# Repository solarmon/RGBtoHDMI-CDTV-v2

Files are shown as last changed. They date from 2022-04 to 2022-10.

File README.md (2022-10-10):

## Introduction

This is **version 2** of the [RGBtoHDMI CDTV](https://github.com/solarmon/RGBtoHDMI-CDTV) solution.

Improvements over version one are:

* Full sized HDMI port
* DB9 mouse and joystick ports
* JP15 toggle switch

This is an RGBtoHDMI solution is based on the original work by **hoglet67** and **IanSB**:

hoglet67:
https://github.com/hoglet67/RGBtoHDMI

IanSB:
https://github.com/IanSB/RGBtoHDMI

The solution is based on the RGBtoHDMI CPLD based hardware design by **LinuxJedi**:

https://github.com/LinuxJedi/AmigaRGBtoHDMI

Special mention to **c0pperdragon** for the original RGBtoHDMI board solution for the Amiga:

https://github.com/c0pperdragon/Amiga-Digital-Video

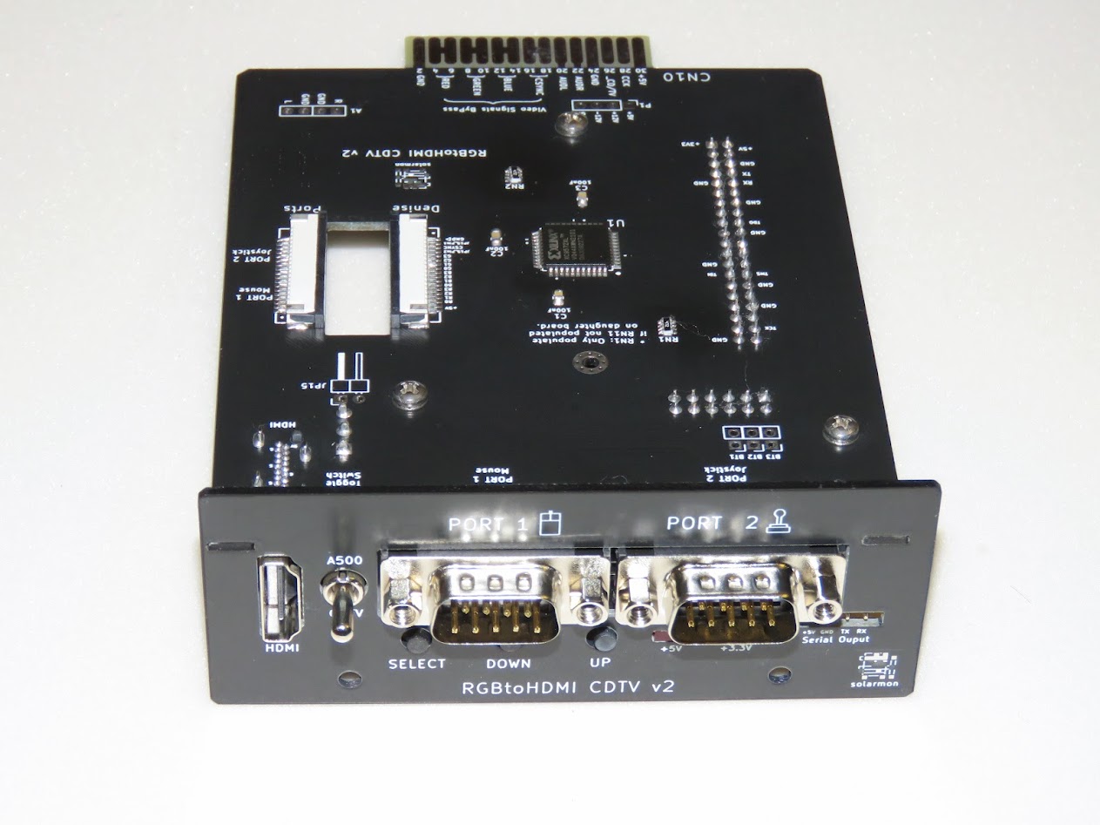
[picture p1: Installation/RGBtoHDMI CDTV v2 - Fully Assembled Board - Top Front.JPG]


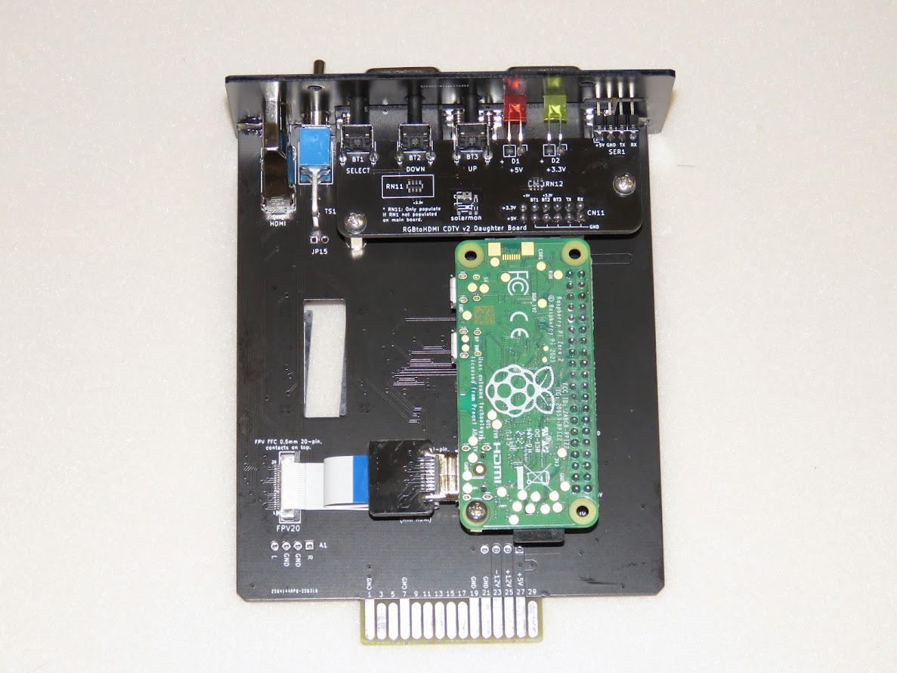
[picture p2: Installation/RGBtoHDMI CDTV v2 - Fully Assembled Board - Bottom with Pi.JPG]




## Design Files

The design files are available for **KiCAD v6**.

### RGBtoHDMI CDTV v2 (QFP)

This is the Xilinx XC9572XL QFP 44-pin package version.

This is the main RGBtoHDMI board, with daughter board, and face plate:

[RGBtoHDMI CDTV v2](https://github.com/solarmon/RGBtoHDMI-CDTV-v2/tree/main/RGBtoHDMI%20CDTV%20v2)

Note: Due to limitations of the 3D rendering in KiCAD, some of the colours and components are not accurate.

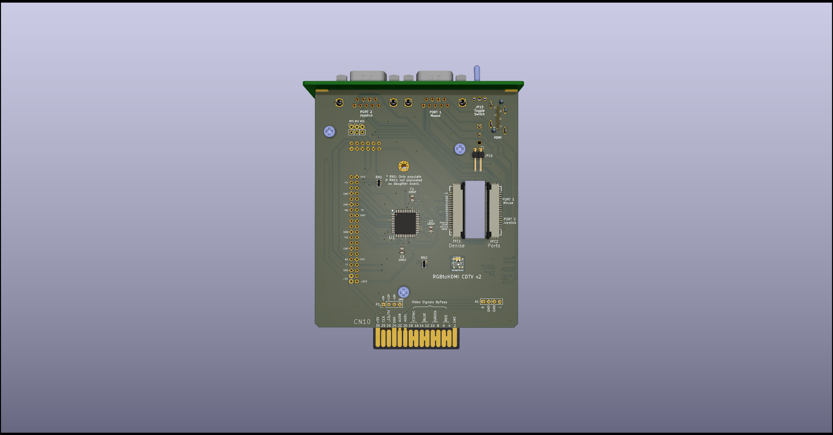
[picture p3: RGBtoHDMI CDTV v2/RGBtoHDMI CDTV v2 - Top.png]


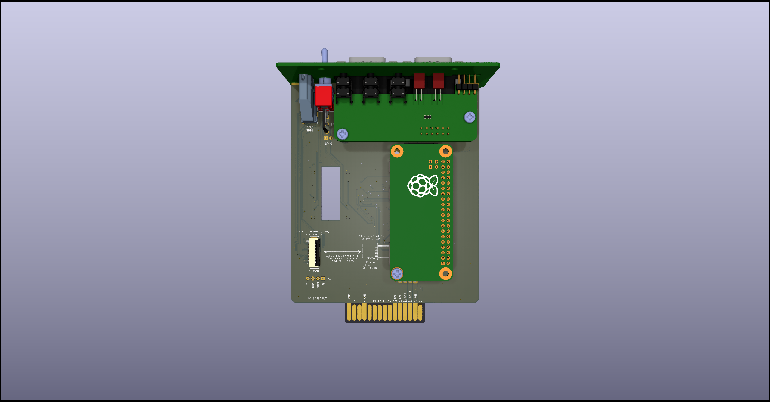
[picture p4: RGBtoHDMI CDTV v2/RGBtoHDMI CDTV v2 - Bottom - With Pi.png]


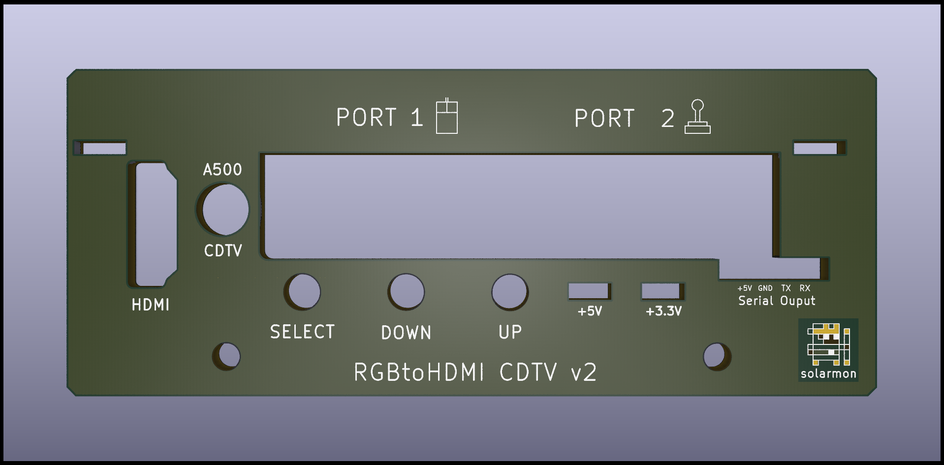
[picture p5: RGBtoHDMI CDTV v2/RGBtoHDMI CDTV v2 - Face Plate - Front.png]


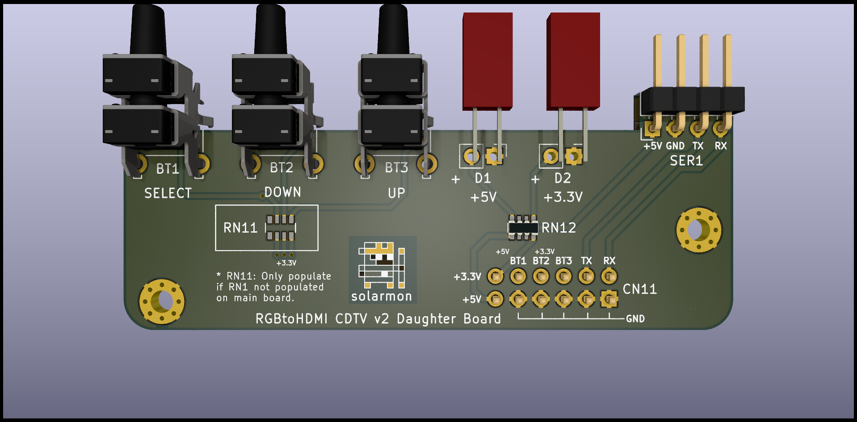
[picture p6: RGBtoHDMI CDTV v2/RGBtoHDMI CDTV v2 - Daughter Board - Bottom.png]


### RGBtoHDMI CDTV v2 - Denise Breakout

This is the Denise adapter that is required to connect to the main board. It provides the digital RGB video and JP15 signals to the main board.

[RGBtoHDMI CDTV v2 - Denise Breakout](https://github.com/solarmon/RGBtoHDMI-CDTV-v2/tree/main/RGBtoHDMI%20CDTV%20v2%20-%20Denise%20Breakout)

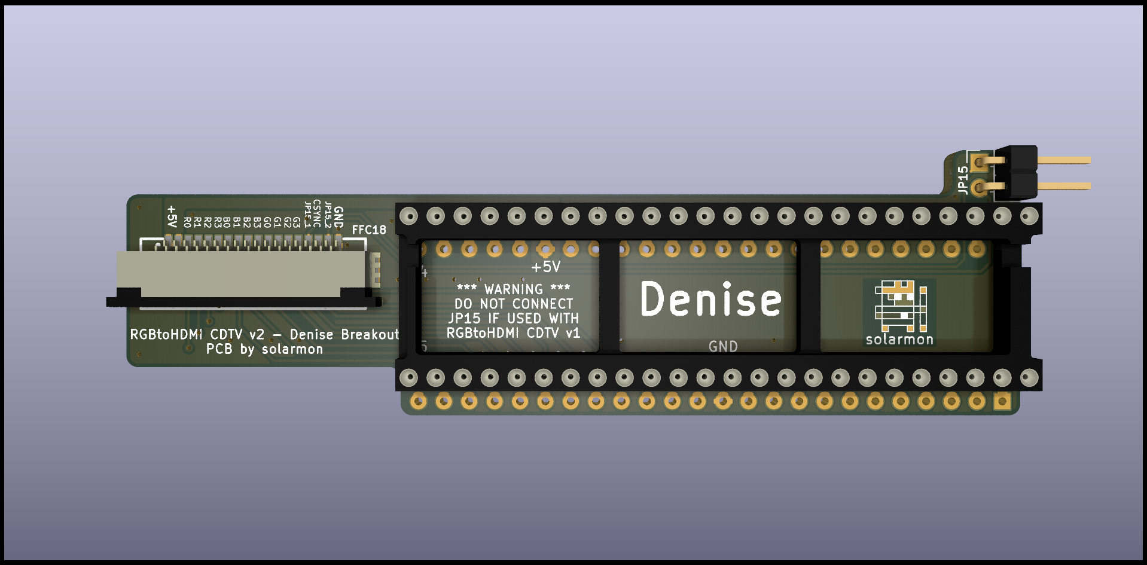
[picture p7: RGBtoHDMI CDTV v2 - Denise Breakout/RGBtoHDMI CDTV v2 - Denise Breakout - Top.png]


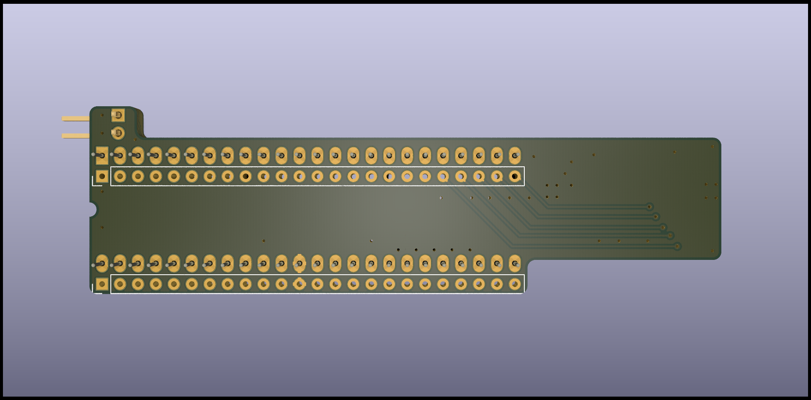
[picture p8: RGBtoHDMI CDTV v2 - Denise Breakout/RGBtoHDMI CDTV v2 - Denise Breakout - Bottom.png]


### RGBtoHDMI CDTV v2 - Mouse and Joystick Adapter

This is the mouse and joystick adapter required to connect to the DB9 ports on the main board:

[RGBtoHDMI CDTV v2 - Mouse and Joystick Adapter](https://github.com/solarmon/RGBtoHDMI-CDTV-v2/tree/main/RGBtoHDMI%20CDTV%20v2%20-%20Mouse%20and%20Joystick%20Adapter)

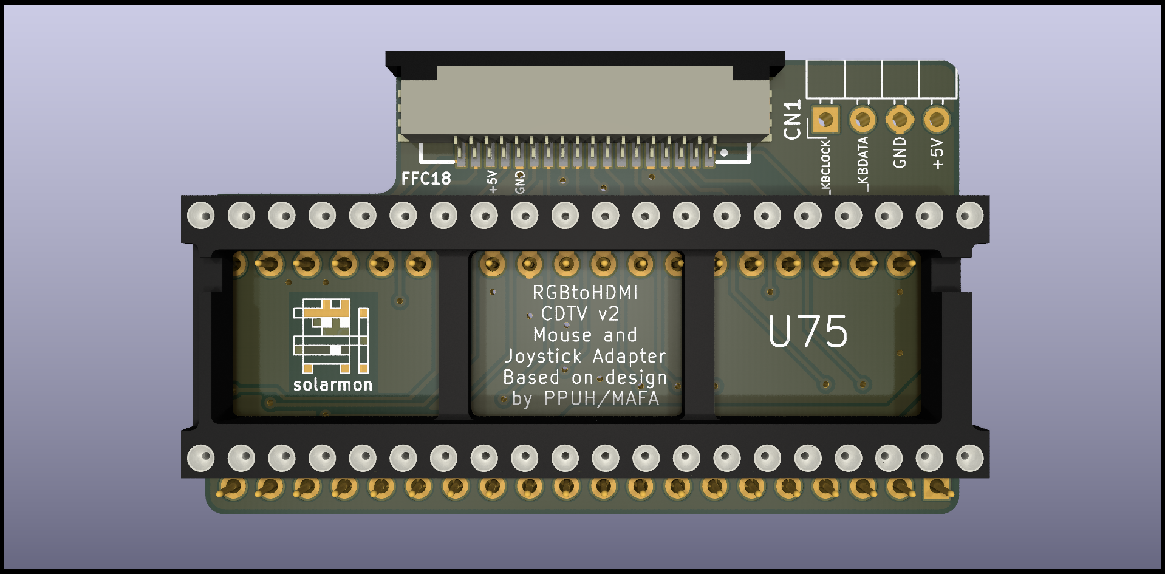
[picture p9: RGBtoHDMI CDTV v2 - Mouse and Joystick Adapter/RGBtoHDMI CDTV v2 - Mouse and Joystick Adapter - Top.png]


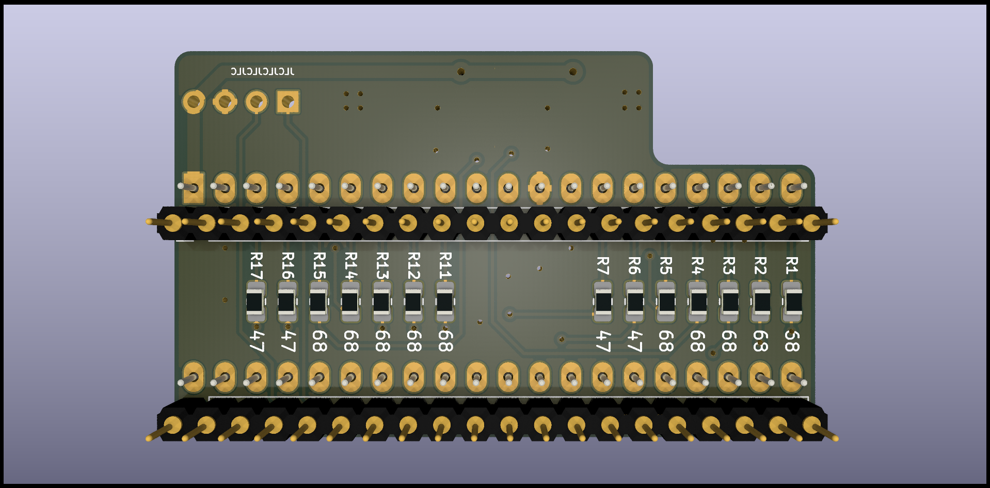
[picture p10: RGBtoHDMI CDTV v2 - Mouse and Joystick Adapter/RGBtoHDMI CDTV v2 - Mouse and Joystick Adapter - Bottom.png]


The adapter uses a 18-pin (1mm pitch) FFC flex cable. A 60cm long flex cable is ideally required. However, if only 30cm long flex cables are available then an FFC extender board can be used to join two of them together:

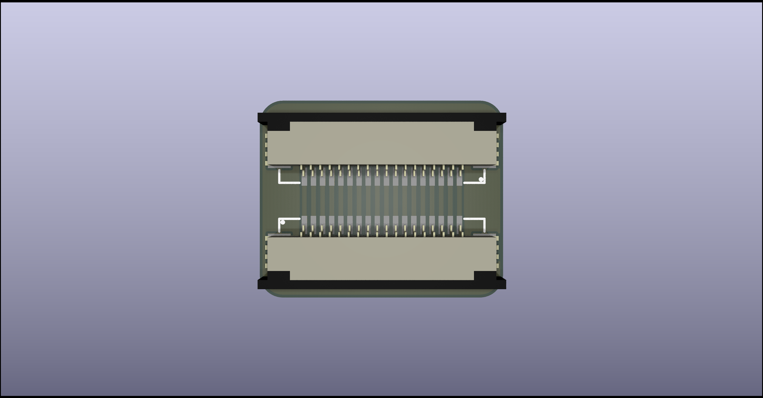
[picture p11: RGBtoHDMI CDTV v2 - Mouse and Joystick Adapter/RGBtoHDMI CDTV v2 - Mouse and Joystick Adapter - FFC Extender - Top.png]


## Wiki

Please see the [wiki](https://github.com/solarmon/RGBtoHDMI-CDTV-v2/wiki) for further details:

[RGBtoHDMI-CDTV-v2-Quick-Start-Guide](https://github.com/solarmon/RGBtoHDMI-CDTV-v2/wiki/RGBtoHDMI-CDTV-v2-Quick-Start-Guide)

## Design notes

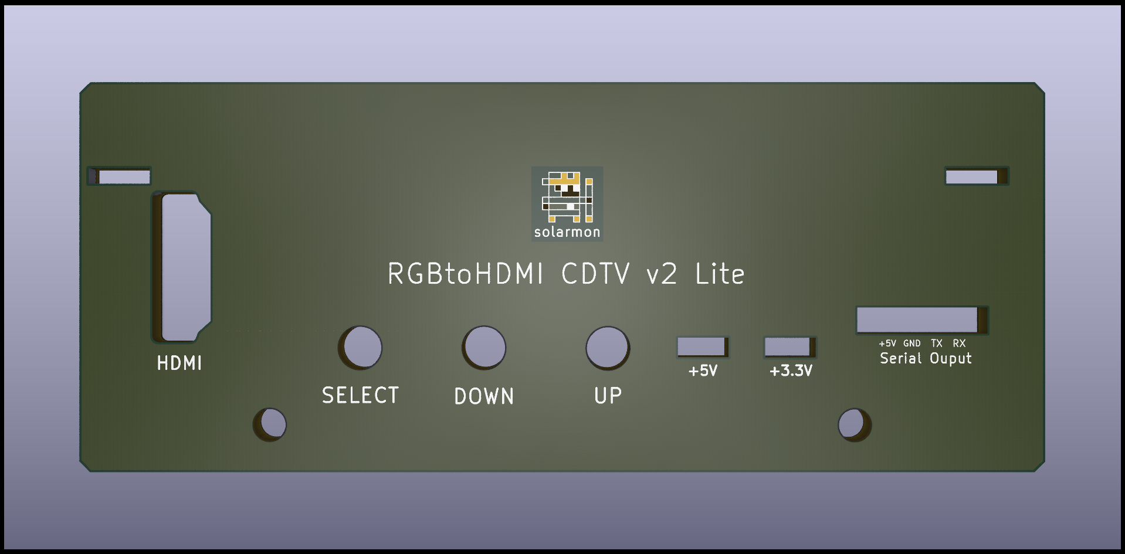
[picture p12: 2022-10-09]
RGBtoHDMI CDTV v2/RGBtoHDMI CDTV v2 - Face Plate - Lite - Front.png

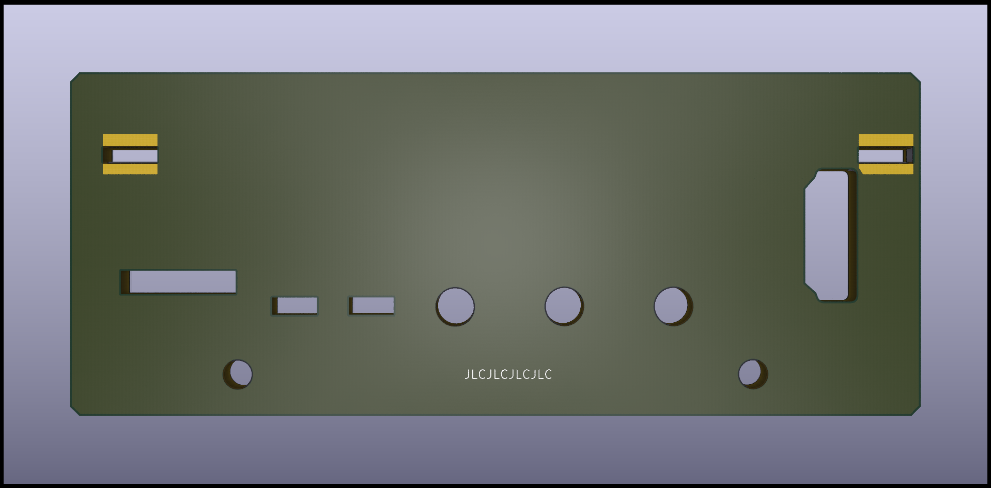
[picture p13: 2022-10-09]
RGBtoHDMI CDTV v2/RGBtoHDMI CDTV v2 - Face Plate - Lite - Back.png

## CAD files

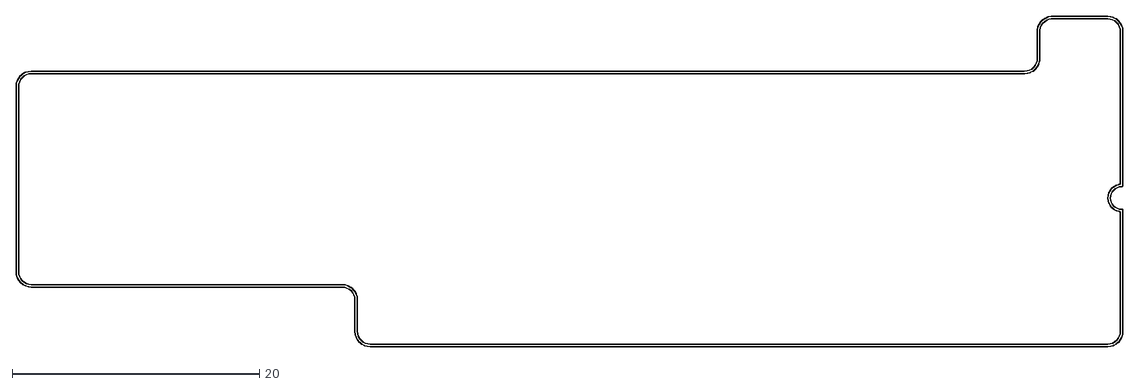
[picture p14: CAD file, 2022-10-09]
RGBtoHDMI CDTV v2 - Denise Breakout/gerber/RGBtoHDMI CDTV v2 - Denise Breakout-Edge_Cuts.dxf
89.6 x 26.7

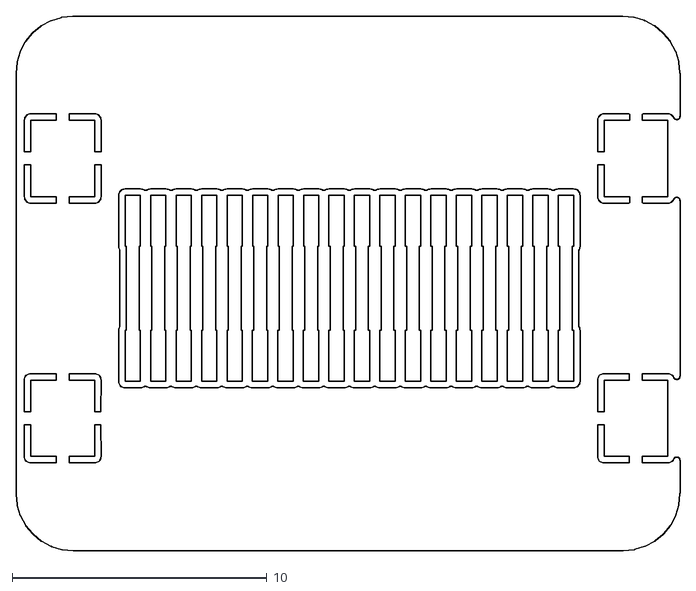
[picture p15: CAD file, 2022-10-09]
RGBtoHDMI CDTV v2 - Mouse and Joystick Adapter/gerber/ffc-extender/RGBtoHDMI CDTV v2 - Mouse and Joystick Adapter - FFC Extender-F_Cu.dxf
26.1 x 21.0

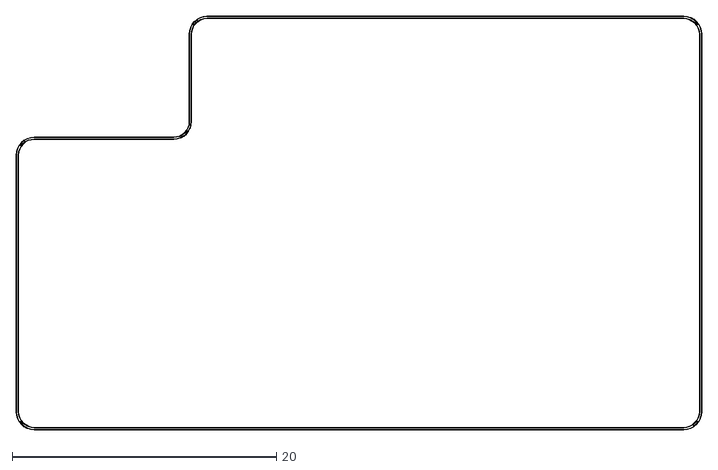
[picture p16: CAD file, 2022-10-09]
RGBtoHDMI CDTV v2 - Mouse and Joystick Adapter/gerber/mouse-joystick-adapter/RGBtoHDMI CDTV v2 - Mouse and Joystick Adapter-Edge_Cuts.dxf
51.8 x 31.3

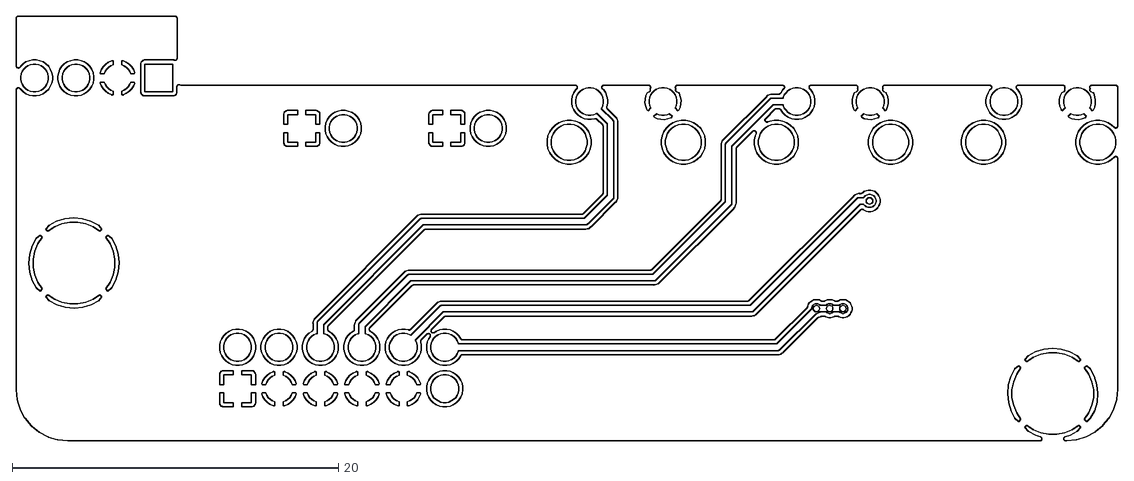
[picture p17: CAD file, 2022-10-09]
RGBtoHDMI CDTV v2/gerbers/daughter-board/RGBtoHDMI CDTV v2 - Daughter Board-F_Cu.dxf
67.5 x 26.0

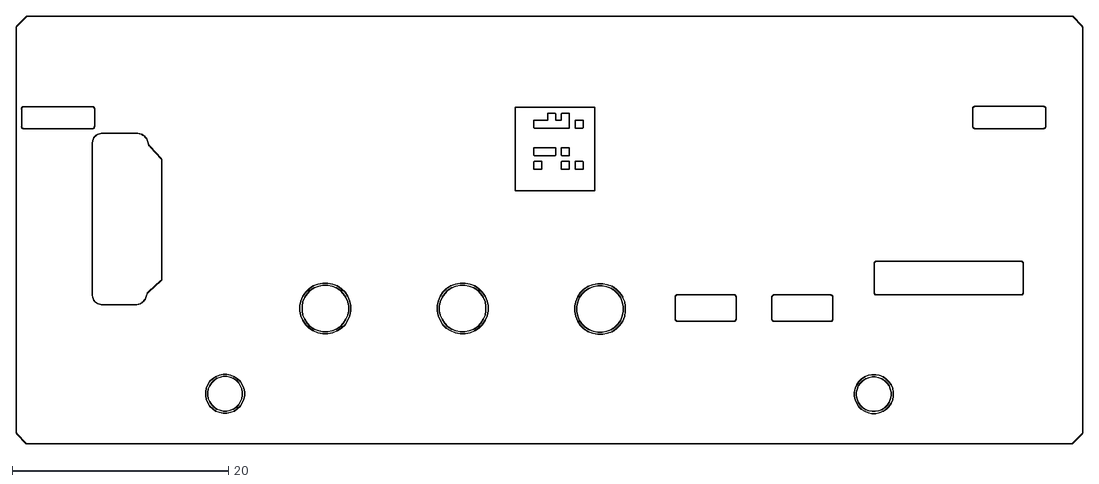
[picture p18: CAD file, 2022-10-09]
RGBtoHDMI CDTV v2/gerbers/face-plate-lite/RGBtoHDMI CDTV v2 - Face Plate - Lite-F_Cu.dxf
98.5 x 39.6

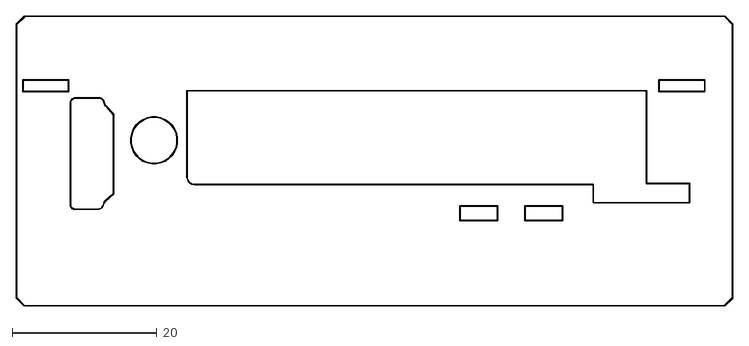
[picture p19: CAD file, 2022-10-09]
RGBtoHDMI CDTV v2/gerbers/face-plate/RGBtoHDMI CDTV v2 - Face Plate-Edge_Cuts.dxf
99.0 x 40.1

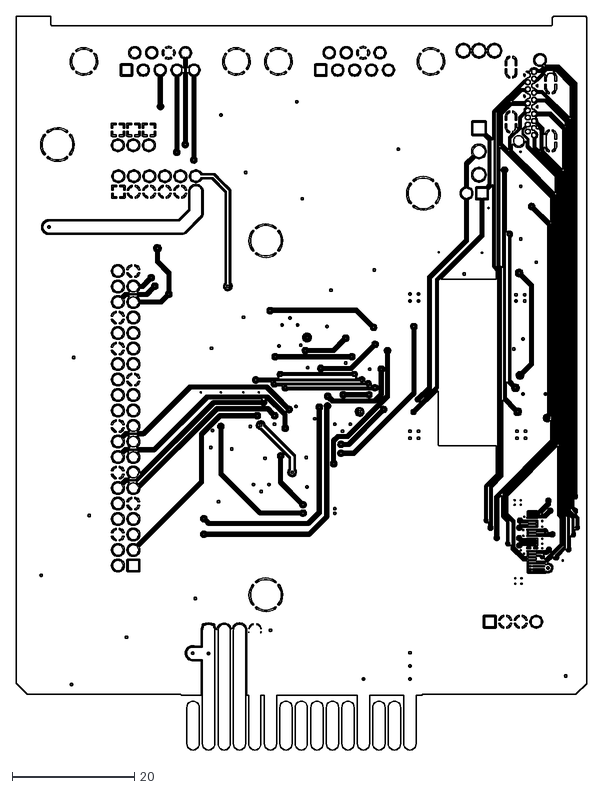
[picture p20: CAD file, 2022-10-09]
RGBtoHDMI CDTV v2/gerbers/video-slot/RGBtoHDMI CDTV v2-B_Cu.dxf
93.5 x 120.3

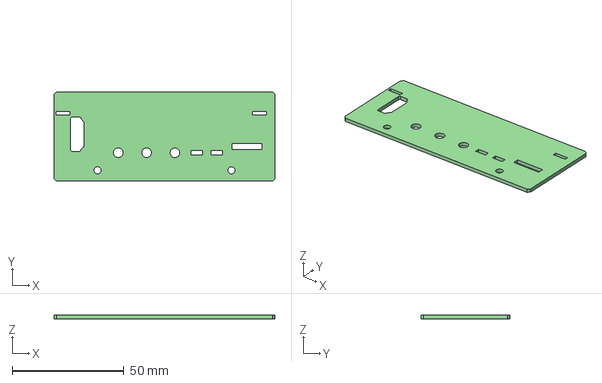
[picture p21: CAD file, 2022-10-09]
RGBtoHDMI CDTV v2/RGBtoHDMI CDTV v2 - Face Plate - Lite.step
99.0 x 40.0 x 1.60 mm

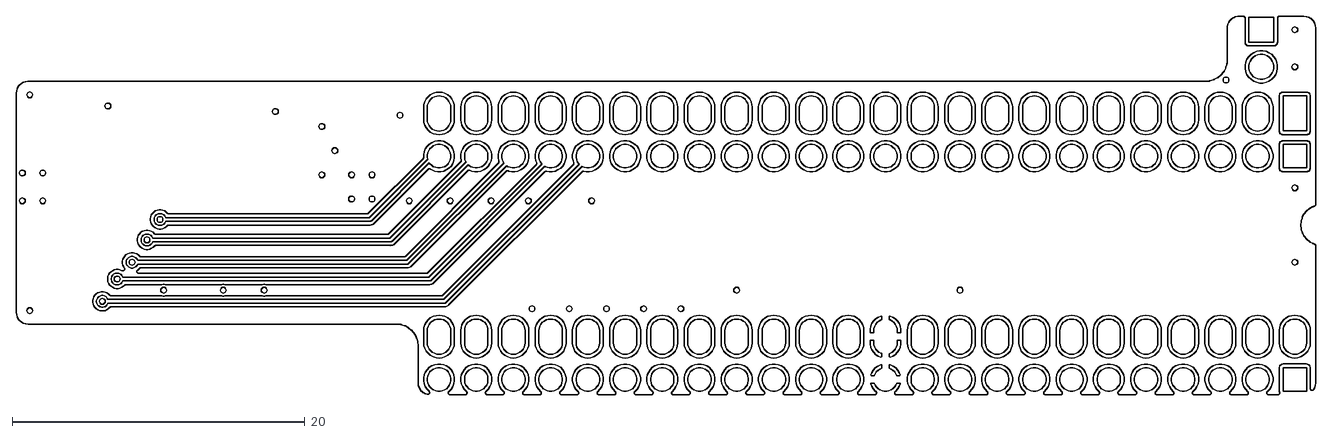
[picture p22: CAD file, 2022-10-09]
RGBtoHDMI CDTV v2 - Denise Breakout/gerber/RGBtoHDMI CDTV v2 - Denise Breakout-B_Cu.dxf
88.7 x 25.8

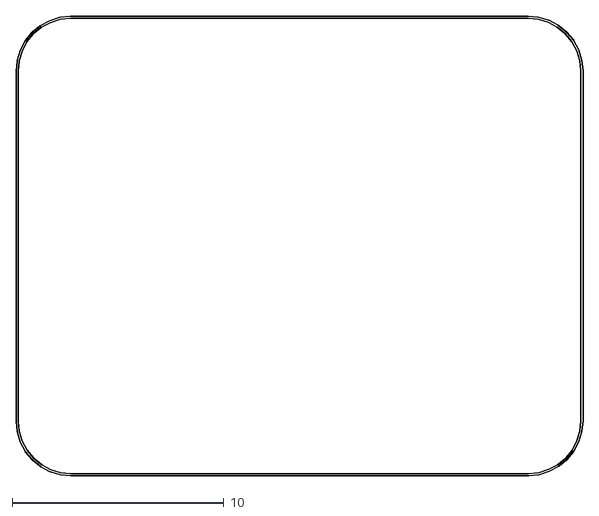
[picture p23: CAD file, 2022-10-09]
RGBtoHDMI CDTV v2 - Mouse and Joystick Adapter/gerber/ffc-extender/RGBtoHDMI CDTV v2 - Mouse and Joystick Adapter - FFC Extender-Edge_Cuts.dxf
26.8 x 21.7

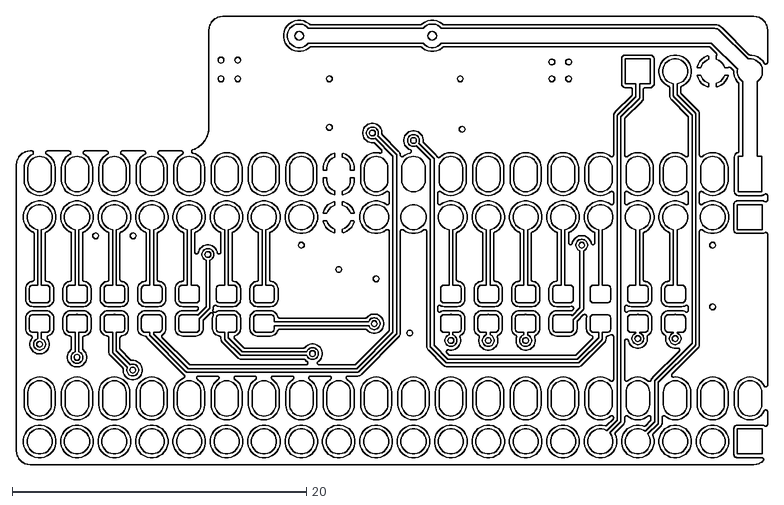
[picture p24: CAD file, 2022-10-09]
RGBtoHDMI CDTV v2 - Mouse and Joystick Adapter/gerber/mouse-joystick-adapter/RGBtoHDMI CDTV v2 - Mouse and Joystick Adapter-B_Cu.dxf
51.0 x 30.5

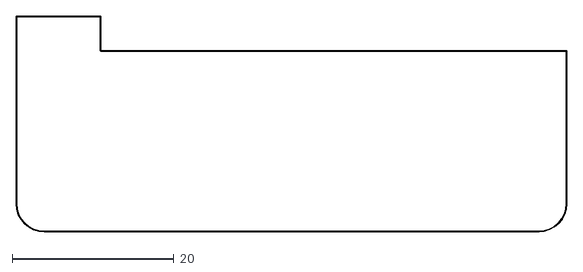
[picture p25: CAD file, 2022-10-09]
RGBtoHDMI CDTV v2/gerbers/daughter-board/RGBtoHDMI CDTV v2 - Daughter Board-Edge_Cuts.dxf
68.1 x 26.6

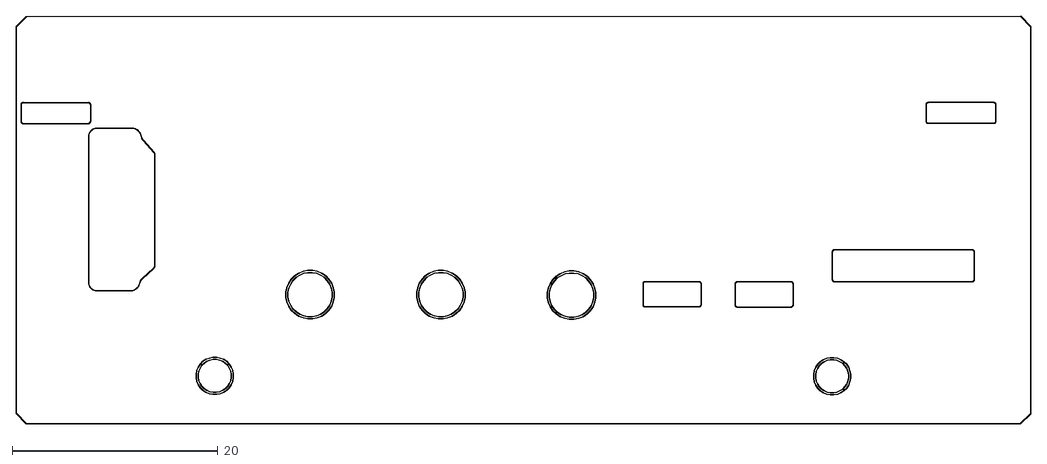
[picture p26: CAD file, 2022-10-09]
RGBtoHDMI CDTV v2/gerbers/face-plate-lite/RGBtoHDMI CDTV v2 - Face Plate - Lite-B_Cu.dxf
98.5 x 39.6

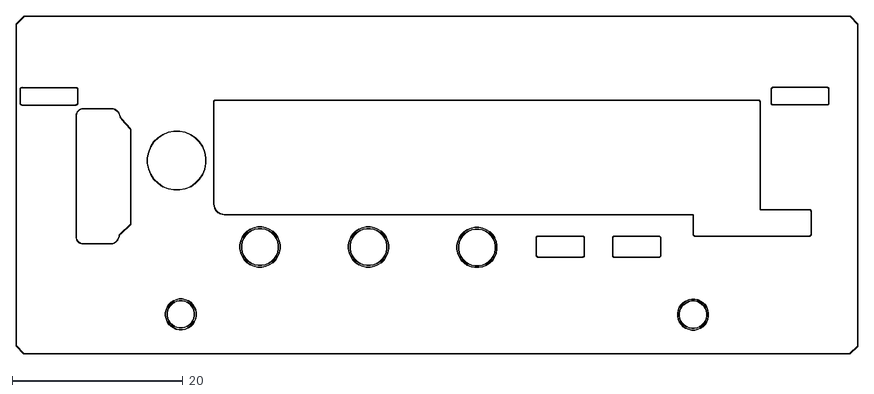
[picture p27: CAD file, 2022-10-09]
RGBtoHDMI CDTV v2/gerbers/face-plate/RGBtoHDMI CDTV v2 - Face Plate-B_Cu.dxf
98.5 x 39.6

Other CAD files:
RGBtoHDMI CDTV v2/gerbers/video-slot/RGBtoHDMI CDTV v2-Edge_Cuts.dxf
RGBtoHDMI CDTV v2/RGBtoHDMI CDTV v2 - Face Plate.step
RGBtoHDMI CDTV v2 - Denise Breakout/gerber/RGBtoHDMI CDTV v2 - Denise Breakout-F_Cu.dxf
RGBtoHDMI CDTV v2 - Mouse and Joystick Adapter/gerber/ffc-extender/RGBtoHDMI CDTV v2 - Mouse and Joystick Adapter - FFC Extender-B_Cu.dxf
RGBtoHDMI CDTV v2 - Denise Breakout/gerber/RGBtoHDMI CDTV v2 - Denise Breakout-B_Mask.dxf
RGBtoHDMI CDTV v2 - Denise Breakout/gerber/RGBtoHDMI CDTV v2 - Denise Breakout-B_SilkS.dxf
RGBtoHDMI CDTV v2 - Denise Breakout/gerber/RGBtoHDMI CDTV v2 - Denise Breakout-F_Mask.dxf
RGBtoHDMI CDTV v2 - Denise Breakout/gerber/RGBtoHDMI CDTV v2 - Denise Breakout-F_SilkS.dxf
RGBtoHDMI CDTV v2 - Mouse and Joystick Adapter/gerber/ffc-extender/RGBtoHDMI CDTV v2 - Mouse and Joystick Adapter - FFC Extender-B_Mask.dxf
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

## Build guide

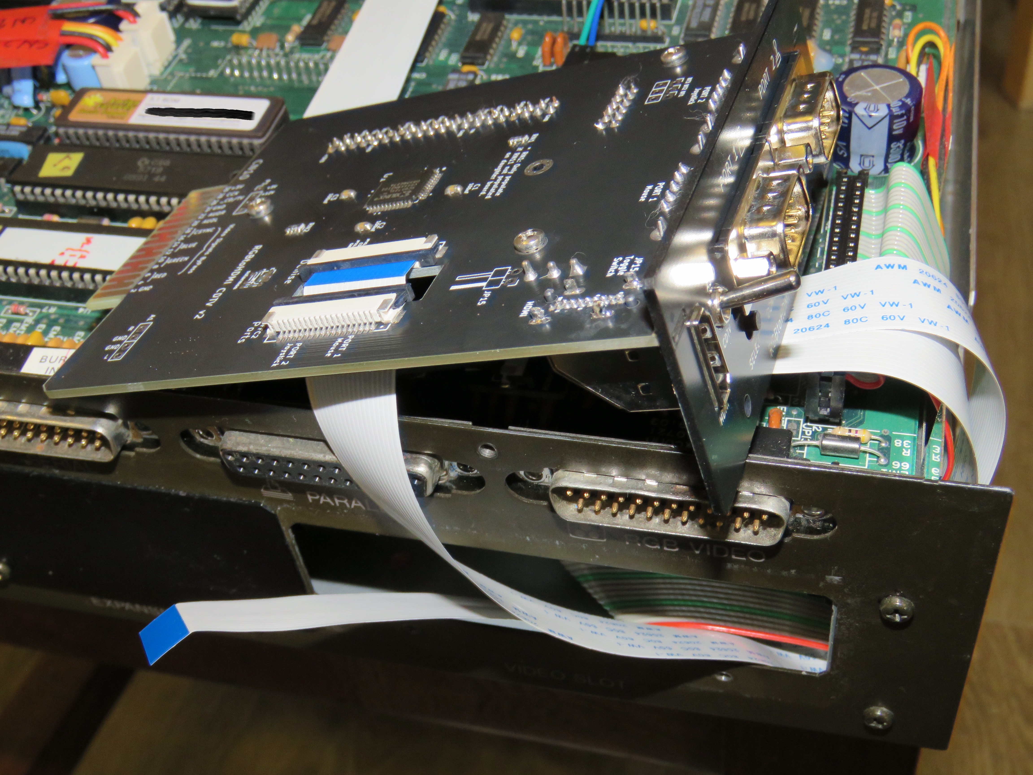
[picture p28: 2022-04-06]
Installation/RGBtoHDMI CDTV v2 - Main Board - Denise Adapter Cable.JPG

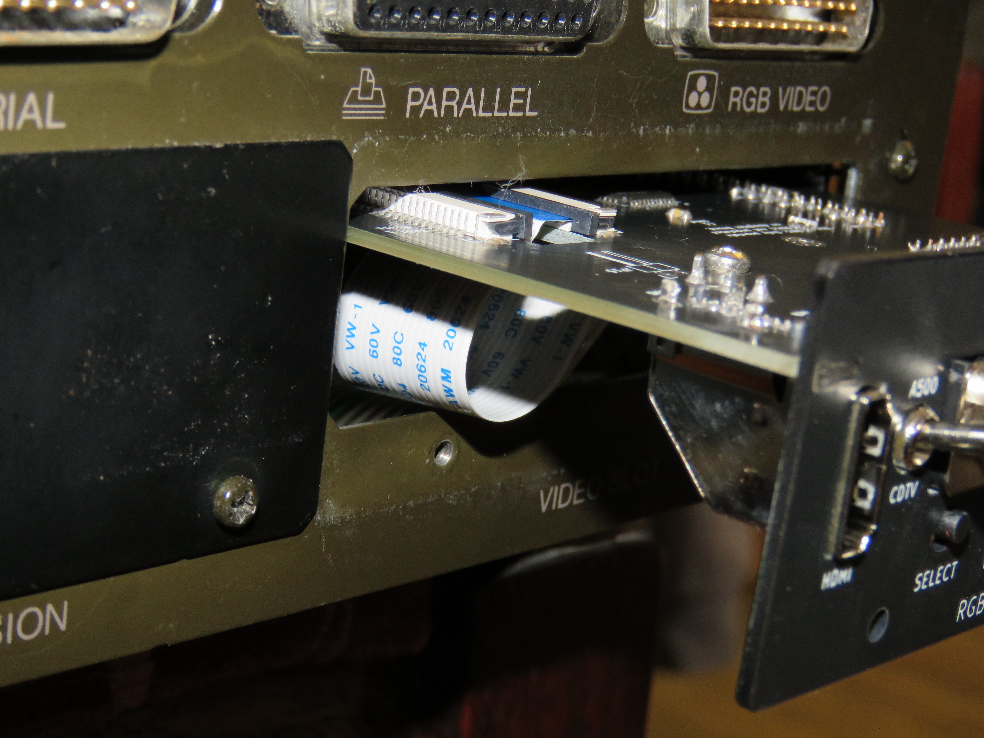
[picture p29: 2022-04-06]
Installation/RGBtoHDMI CDTV v2 - Main Board - Flex Cable Warning 2.JPG

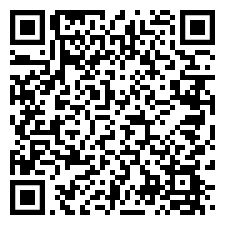
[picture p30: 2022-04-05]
RGBtoHDMI CDTV v2/RGBtoHDMI-CDTV-v2-Quick-Start-Guide.png

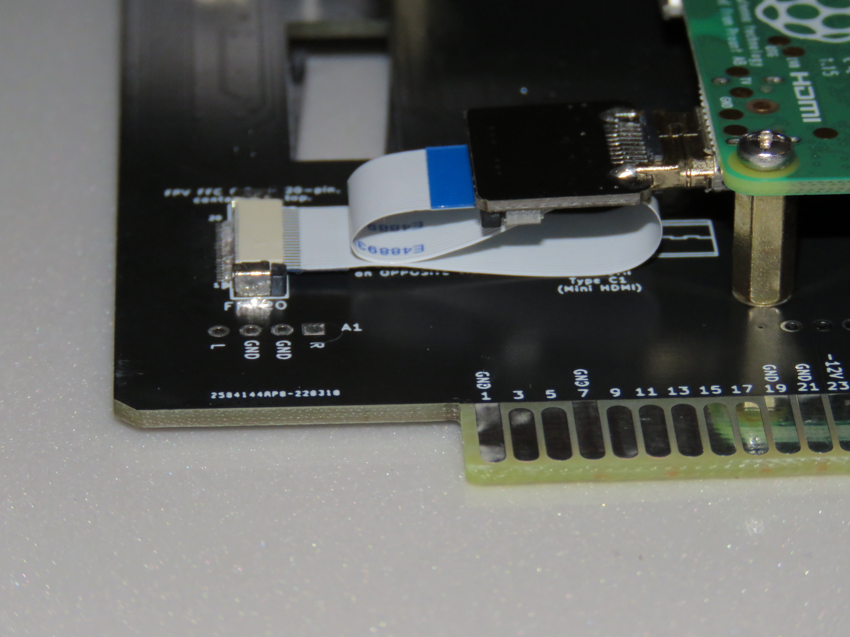
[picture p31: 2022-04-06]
Installation/RGBtoHDMI CDTV v2 - Mini HDMI FPV Connector - Side.JPG

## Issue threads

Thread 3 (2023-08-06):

CDTV RGB2HDMI v2 (SOIC) - Joystick Fire, and rear Up & Down not working.

Korinel, 2023-08-06:
I have the CDTV RGB2HDMI v2 (SOIC) and just installed it. The issue is that the Down and Up buttons on the rear do not function (Select is fine) and the fire button on joystick port does not work either. Everything else works fine. Using CDTV Remote and a Brickette joystick cable the button works fine. I have tried with four joysticks, all the same. Fire button 2 and 3 work fine on joystick just not Fire button one. Defective card or installation issue? Anything connected with these three buttons? Any help with diagnoses would be fab!

solarmon, 2023-08-06:
Hi,

I'm sorry to hear that you have issues with your RGBtoHDMI board.

Please can you contact me on the channel you purchased it from.

Korinel, 2023-08-24:
All fixed, thanks!

Closed 2023-08-24.

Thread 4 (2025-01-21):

CD32 compatible pad support

arczi84, 2025-01-21:
It's a shame that not all pins in DB9 port are connected which makes this interface not working for all buttons in Cd32 compatible game pads.
I hope that full interface would be available in next revision and separate joy only extension is available to update for current v2 owners.

solarmon, 2025-01-21:
@arczi84

What pins are you specifically referring too?

solarmon, 2025-01-22:
@arczi84

I haven't got a CD32 joypad to test/check.

What program did you test it with?

Please use Amiga Test Kit - that has a CD32 mode.

arczi84, 2025-01-22:
https://aminet.net/package/driver/input/JoyPortTest Works fine on A500 with
cd32 pad.

śr., 22 sty 2025, 14:11 użytkownik solarmon ***@***.***>
napisał:

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

solarmon, 2025-01-22:
@arczi84

Please can you try testing with Amiga Test Kit on the CDTV.

solarmon, 2025-01-26:
@arczi84

I assume a normal joystick works as expected, and it is only FIRE2 (and the rest of the CD32 joypad buttons) that is not working as expected?

The joystick/mouse adapter than comes with the RGBtoHDMI CDTV v2 solution does map all nine pins for each port.

I don't have a CD32 joypad to test with, but my understanding is that the CD32 joypad use pin 5 to determine whether to be in normal/dump joystick mode, or 7-button joystick mode. See https://www.mrdictionary.net/PSCD32/diary/2019_08_09.htm

Have you tried using ATK to test both ports, in CD32 mode?

If you have a logic probe, you can check what pin 5 is doing - whether it is high or low.

Closed 2025-05-17.

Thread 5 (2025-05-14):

Audio Support

a1exh, 2025-05-14:
A miniature audio ADC addon board has been created by the original RGBTOHDMI developers

https://github.com/hoglet67/RGBtoHDMI/wiki/Audio

How easy would it be to integrate one with the CDTV v2? Is Analog audio L/R/GND easily available to wire to this board? (I think the V1 used to have pads for these signals?)

Thanks for reading.

solarmon, 2025-05-17:
Got one of those audio boards today.

Quickly checked physical placement of them on the three different RGBtoHDMI CDTV v2 models.

TQFP:

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

PLCC:

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

SOIC:

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

On the TQFP and PLCC models, the audio board fits perfectly. On the SOIC model, the audio board sits at an angle, but looks like it should be OK.

Need to find some time to test it - probably on the PLCC one as this is what I have mostly built.

solarmon, 2025-05-17:
I was able to test with the PLCC board (although, only with an A500+ board - since my CDTV isn't booting up).

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

It seems to be working nicely!

Interestingly, from looking at the schematics, it looks like the CD audio (CDAL and CDAR) is also mixed in with the Paula audio, and the output (AUDL and AUDLR) is what is presented to the video out connector:

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

braykout, 2025-05-25:
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

I installed the audio add-on board in my CDTV, and CD audio and Paula audio are now output via HDMI. CD audio sounds perfect, but unfortunately, Paula audio is clipping and noisy. I have no idea if this is due to my CDTV or the fact that it's still in beta.

braykout, 2025-05-26:
Thanks for the tip about the Alfa version, I was using beta 66 and will try that out and if I have any further problems I'll open an issue on IanSB's Github.

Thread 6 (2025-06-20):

Black display with scsi controller

Piemmeweb, 2025-06-20:
Hi, I'm experiencing a problem with the RGB2HDMI V2 + CDTV SCSI Controller; when the controller is inserted in its slot, I receive a black screen on power up. The machine works because the gotek loads correctly but nothing on the display, seems it doesn't starts properly before the scsi controller.  The machine works fine with the original video controller (composite). I was playing with the setup menu, I have been changed the HDMI AUTO set to manual to jump the autodetecting but I'm still in trouble with it.

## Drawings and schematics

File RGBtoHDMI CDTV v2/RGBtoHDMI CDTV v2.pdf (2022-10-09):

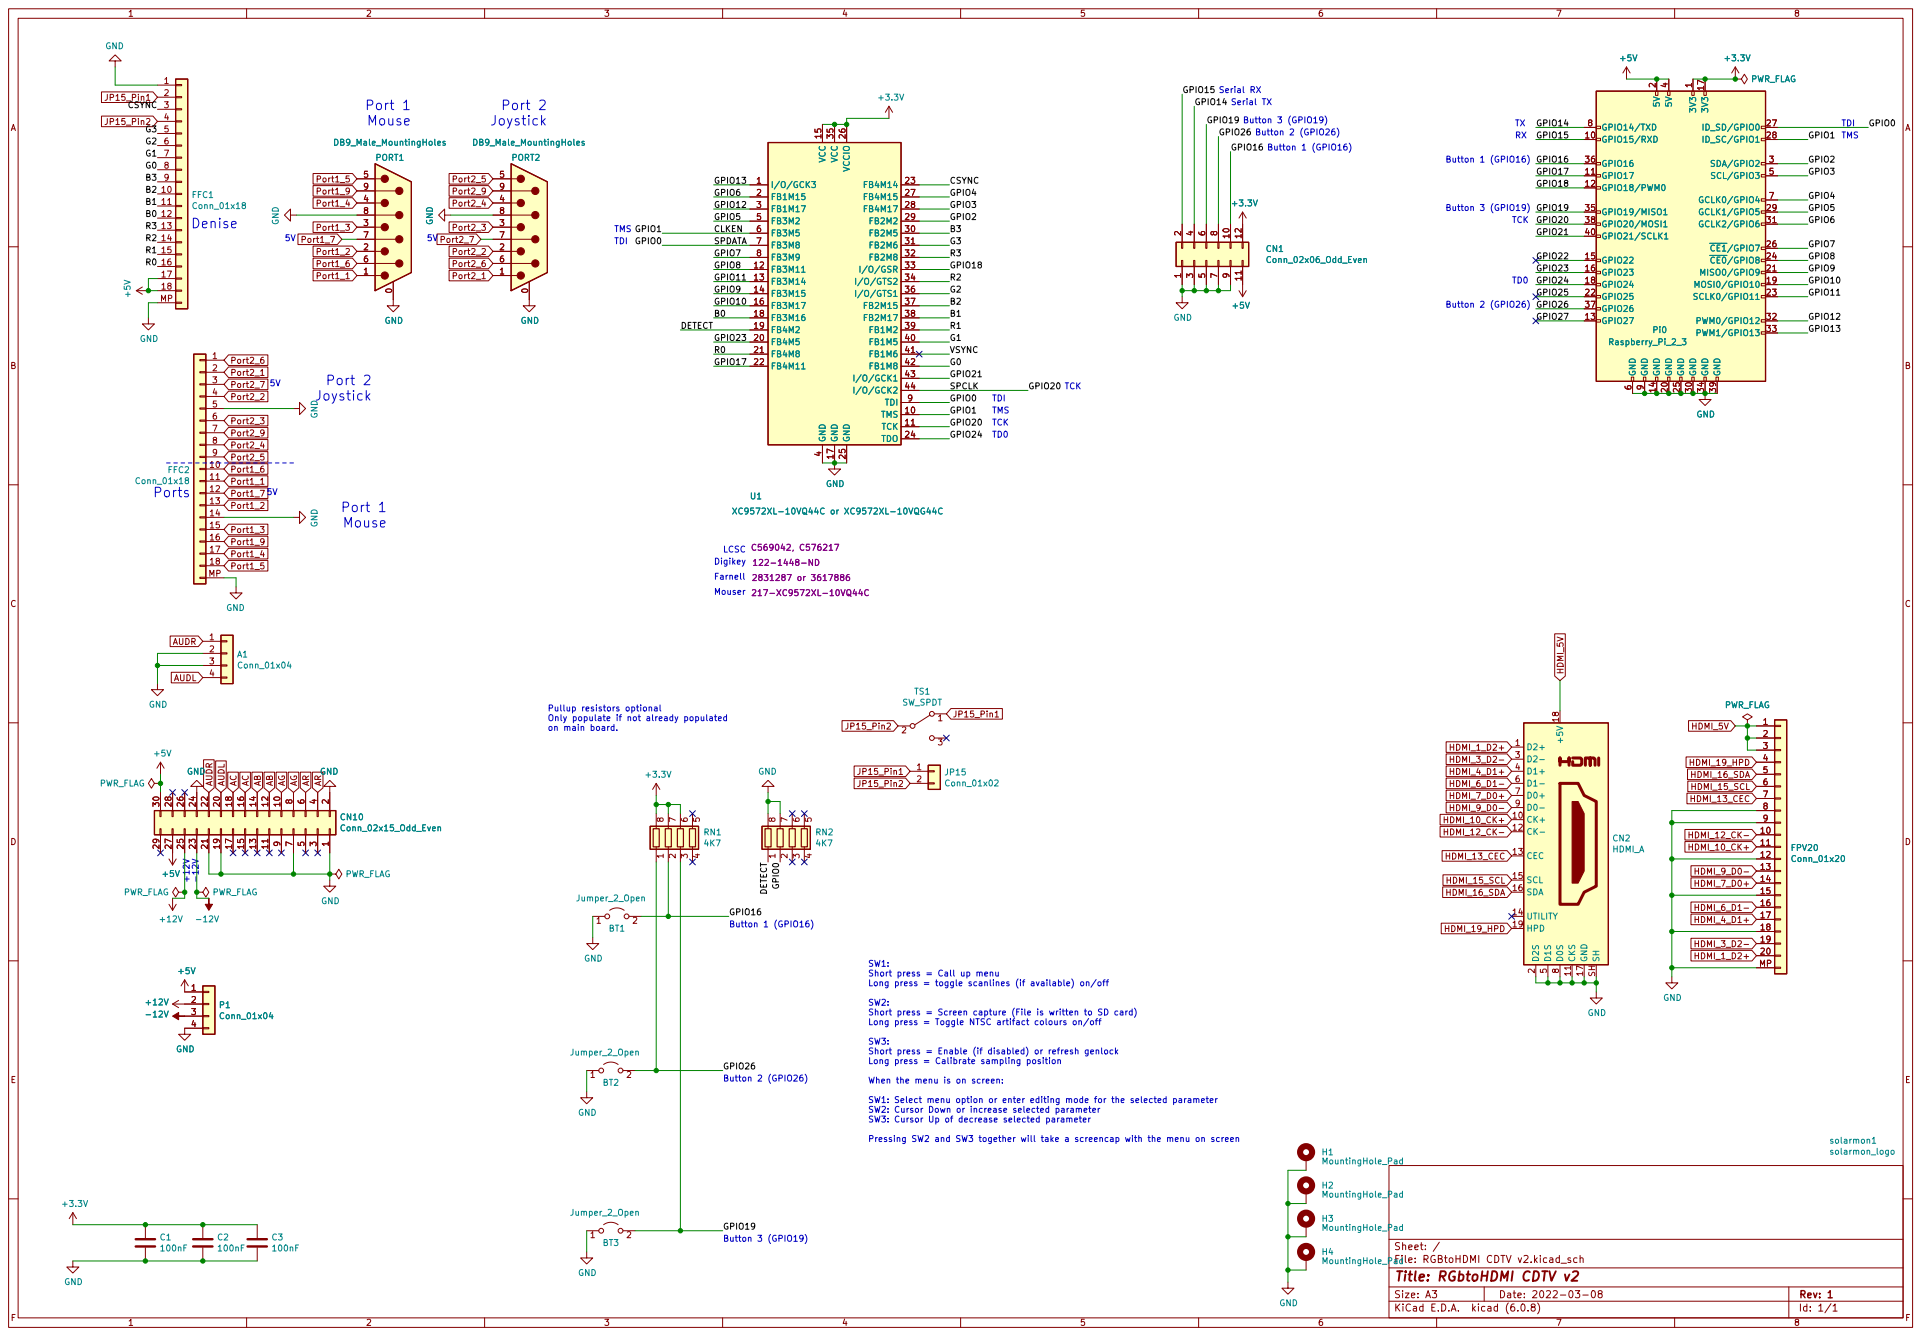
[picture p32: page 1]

Button 1 (GPIO16) Serial RX
TX Button 3 (GPIO19) Serial TX

Farnell Digikey Mouser LCSC

Pullup resistors optional
Only populate if not already populated

SW1: Short press = Call up menu

Long press = toggle scanlines (if available) on/off SW2: Short press = Screen capture (File is written to SD card)

Long press = Toggle NTSC artifact colours on/off SW3: Short press = Enable (if disabled) or refresh genlock

Long press = Calibrate sampling position When the menu is on screen: SW1: Select menu option or enter editing mode for the selected parameter

SW2: Cursor Down or increase selected parameter
SW3: Cursor Up of decrease selected parameter

Pressing SW2 and SW3 together will take a screencap with the menu on screen

File: RGBtoHDMI CDTV v2.kicad_sch Sheet: /
Id: 1/1 Title: RGbtoHDMI CDTV v2

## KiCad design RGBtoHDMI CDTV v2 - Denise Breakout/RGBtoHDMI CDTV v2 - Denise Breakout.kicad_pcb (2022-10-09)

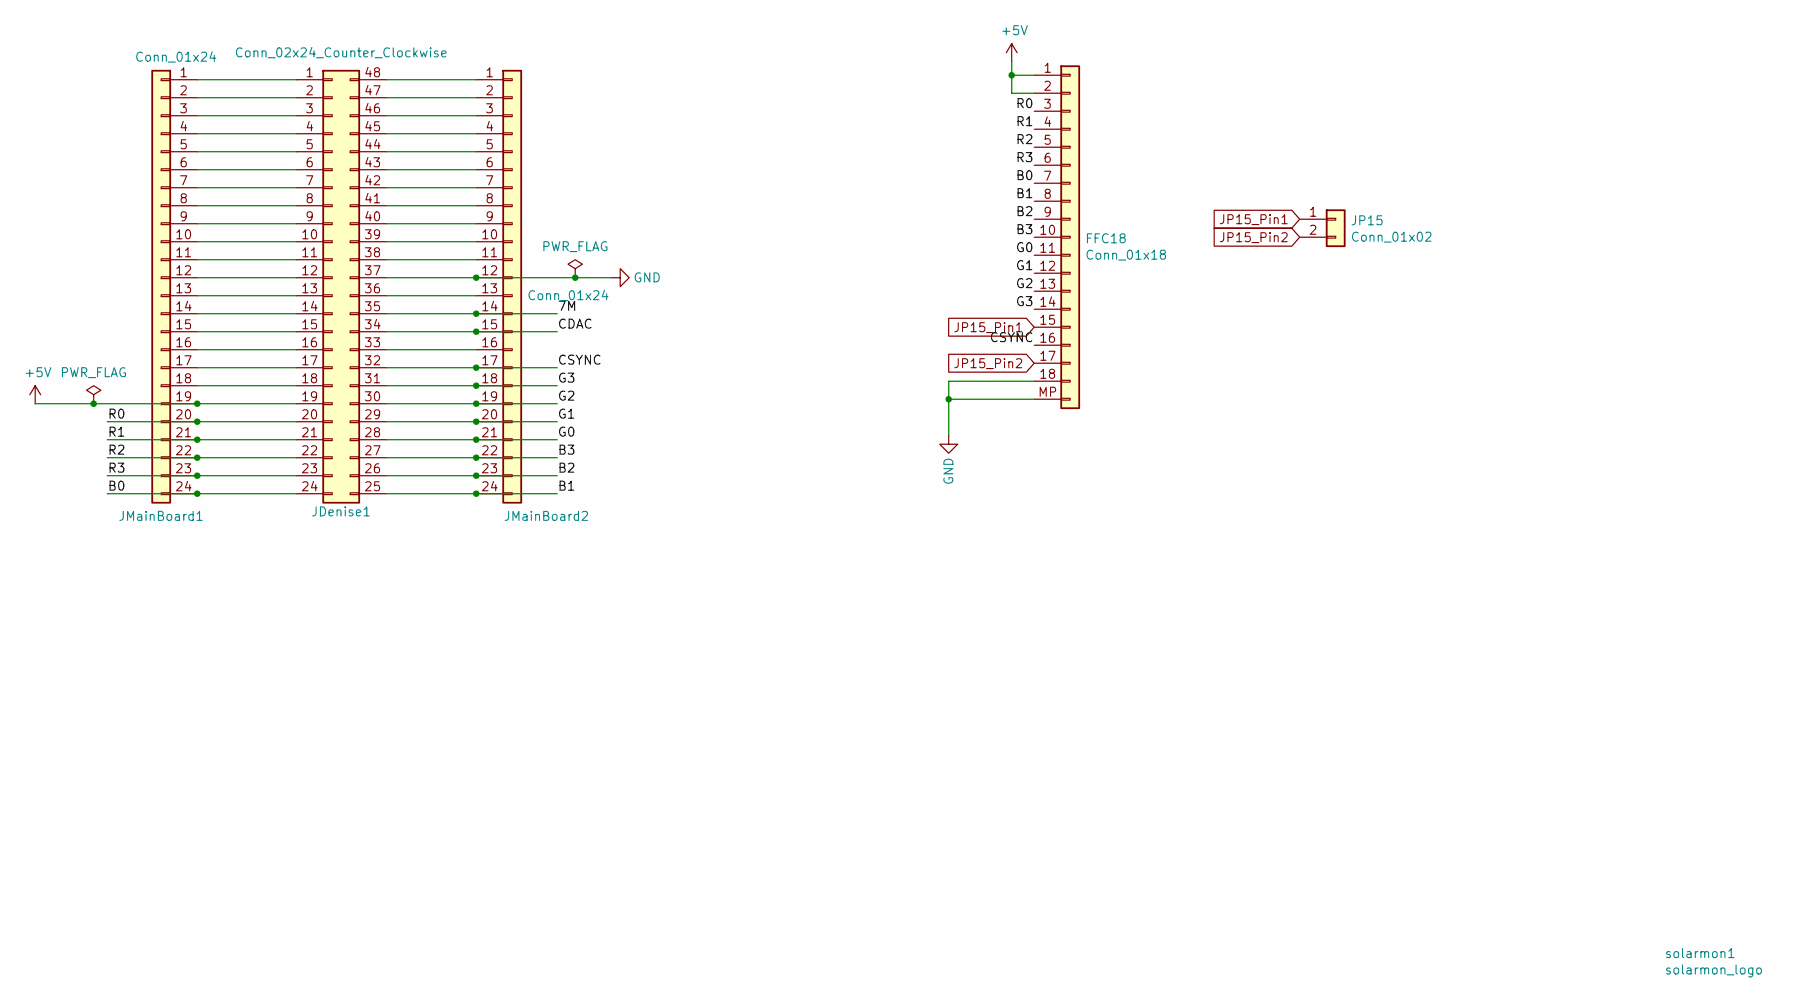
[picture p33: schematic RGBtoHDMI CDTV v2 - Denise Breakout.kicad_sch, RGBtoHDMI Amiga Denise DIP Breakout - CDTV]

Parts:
FFC18: Conn_01x18; FPC-SMD_X10B25U18T
JDenise1: Conn_02x24_Counter_Clockwise; DIP-48_W15.24mm_LongPads
JMainBoard1, JMainBoard2: Conn_01x24; PinHeader_1x24_P2.54mm_Vertical_smaller
JP15: Conn_01x02; PinHeader_1x02_P2.54mm_Horizontal
solarmon1: solarmon_logo; solarmon-logo-25mils

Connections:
+5V: FFC18.1, FFC18.2, JDenise1.19, JMainBoard1.19
/7M: JDenise1.35, JMainBoard2.14
/B0: FFC18.7, JDenise1.24, JMainBoard1.24
/B1: FFC18.8, JDenise1.25, JMainBoard2.24
/B2: FFC18.9, JDenise1.26, JMainBoard2.23
/B3: FFC18.10, JDenise1.27, JMainBoard2.22
/CDAC: JDenise1.34, JMainBoard2.15
/CSYNC: FFC18.16, JDenise1.32, JMainBoard2.17
/G0: FFC18.11, JDenise1.28, JMainBoard2.21
/G1: FFC18.12, JDenise1.29, JMainBoard2.20
/G2: FFC18.13, JDenise1.30, JMainBoard2.19
/G3: FFC18.14, JDenise1.31, JMainBoard2.18
/R0: FFC18.3, JDenise1.20, JMainBoard1.20
/R1: FFC18.4, JDenise1.21, JMainBoard1.21
/R2: FFC18.5, JDenise1.22, JMainBoard1.22
/R3: FFC18.6, JDenise1.23, JMainBoard1.23
GND: FFC18.18, FFC18.MP, JDenise1.37, JMainBoard2.12
JP15_Pin1: FFC18.15, JP15.1
JP15_Pin2: FFC18.17, JP15.2
unnamed: JDenise1.1, JMainBoard1.1
unnamed: JDenise1.2, JMainBoard1.2
unnamed: JDenise1.3, JMainBoard1.3
unnamed: JDenise1.4, JMainBoard1.4
unnamed: JDenise1.5, JMainBoard1.5
unnamed: JDenise1.6, JMainBoard1.6
unnamed: JDenise1.7, JMainBoard1.7
unnamed: JDenise1.8, JMainBoard1.8
unnamed: JDenise1.9, JMainBoard1.9
unnamed: JDenise1.10, JMainBoard1.10
unnamed: JDenise1.11, JMainBoard1.11
unnamed: JDenise1.12, JMainBoard1.12
unnamed: JDenise1.13, JMainBoard1.13
unnamed: JDenise1.14, JMainBoard1.14
unnamed: JDenise1.15, JMainBoard1.15
unnamed: JDenise1.16, JMainBoard1.16
unnamed: JDenise1.17, JMainBoard1.17
unnamed: JDenise1.18, JMainBoard1.18
unnamed: JDenise1.33, JMainBoard2.16
unnamed: JDenise1.36, JMainBoard2.13
unnamed: JDenise1.38, JMainBoard2.11
unnamed: JDenise1.39, JMainBoard2.10
unnamed: JDenise1.40, JMainBoard2.9
unnamed: JDenise1.41, JMainBoard2.8
unnamed: JDenise1.42, JMainBoard2.7
unnamed: JDenise1.43, JMainBoard2.6
unnamed: JDenise1.44, JMainBoard2.5
unnamed: JDenise1.45, JMainBoard2.4
unnamed: JDenise1.46, JMainBoard2.3
unnamed: JDenise1.47, JMainBoard2.2
unnamed: JDenise1.48, JMainBoard2.1

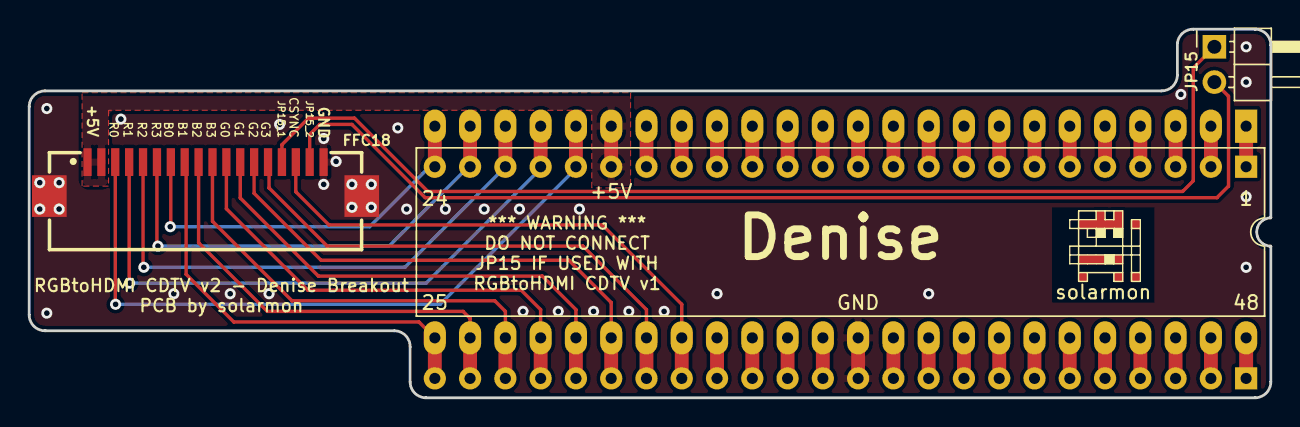
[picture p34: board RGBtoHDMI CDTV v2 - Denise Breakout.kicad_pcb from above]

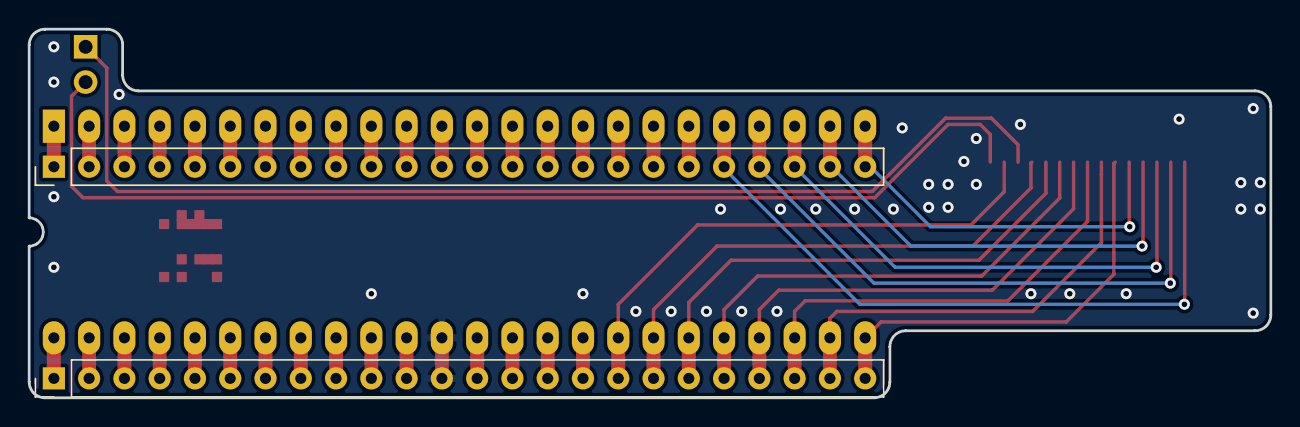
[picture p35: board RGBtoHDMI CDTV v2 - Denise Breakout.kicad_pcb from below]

Board: 2 copper layers, 89.4 x 26.5 mm, 6 parts (2 on the bottom side), 50 nets.

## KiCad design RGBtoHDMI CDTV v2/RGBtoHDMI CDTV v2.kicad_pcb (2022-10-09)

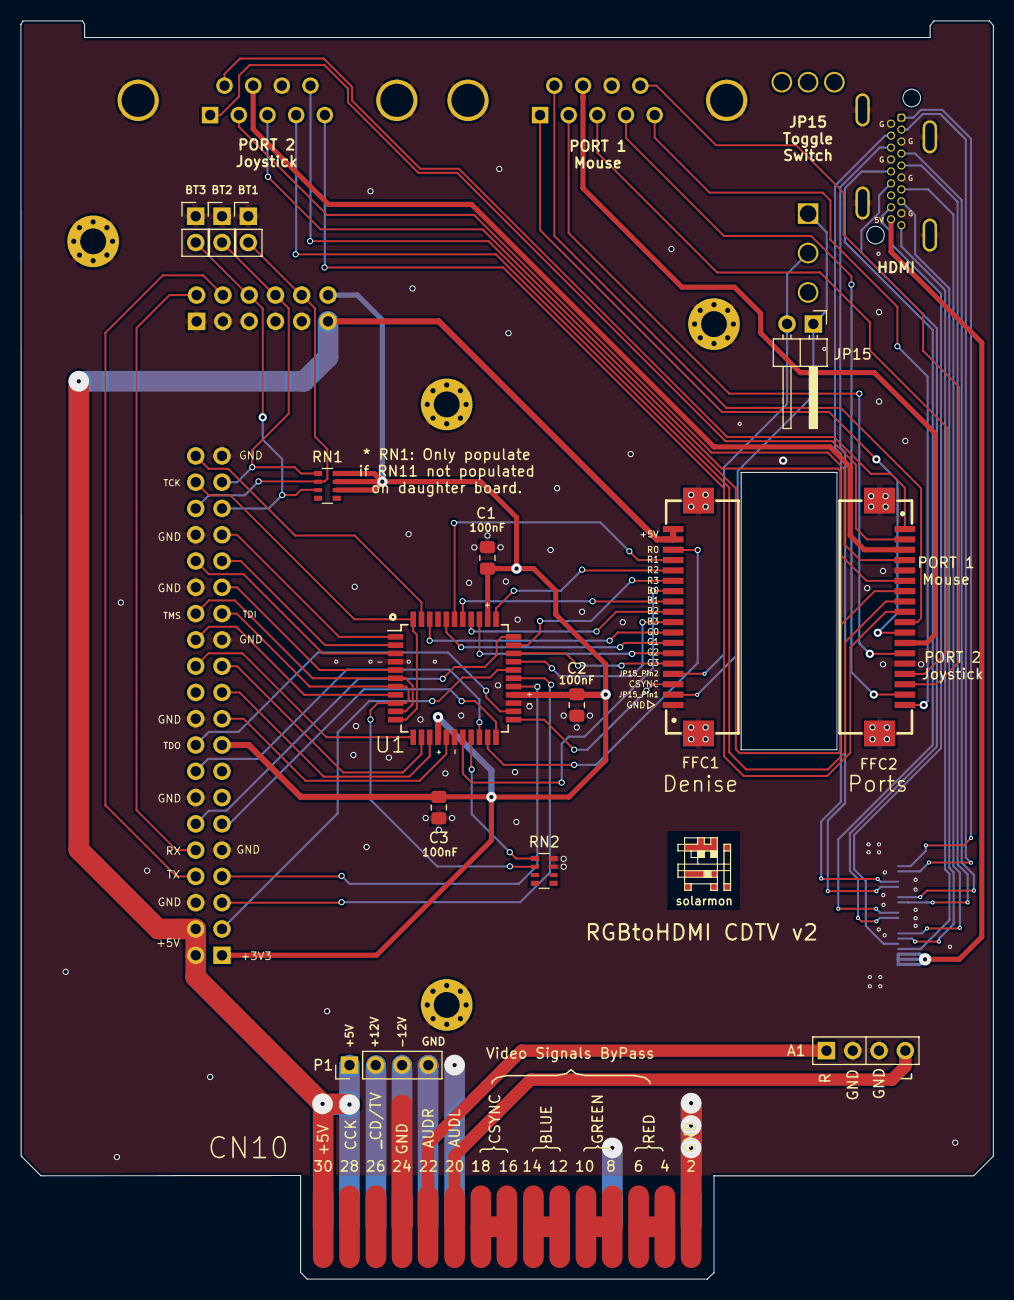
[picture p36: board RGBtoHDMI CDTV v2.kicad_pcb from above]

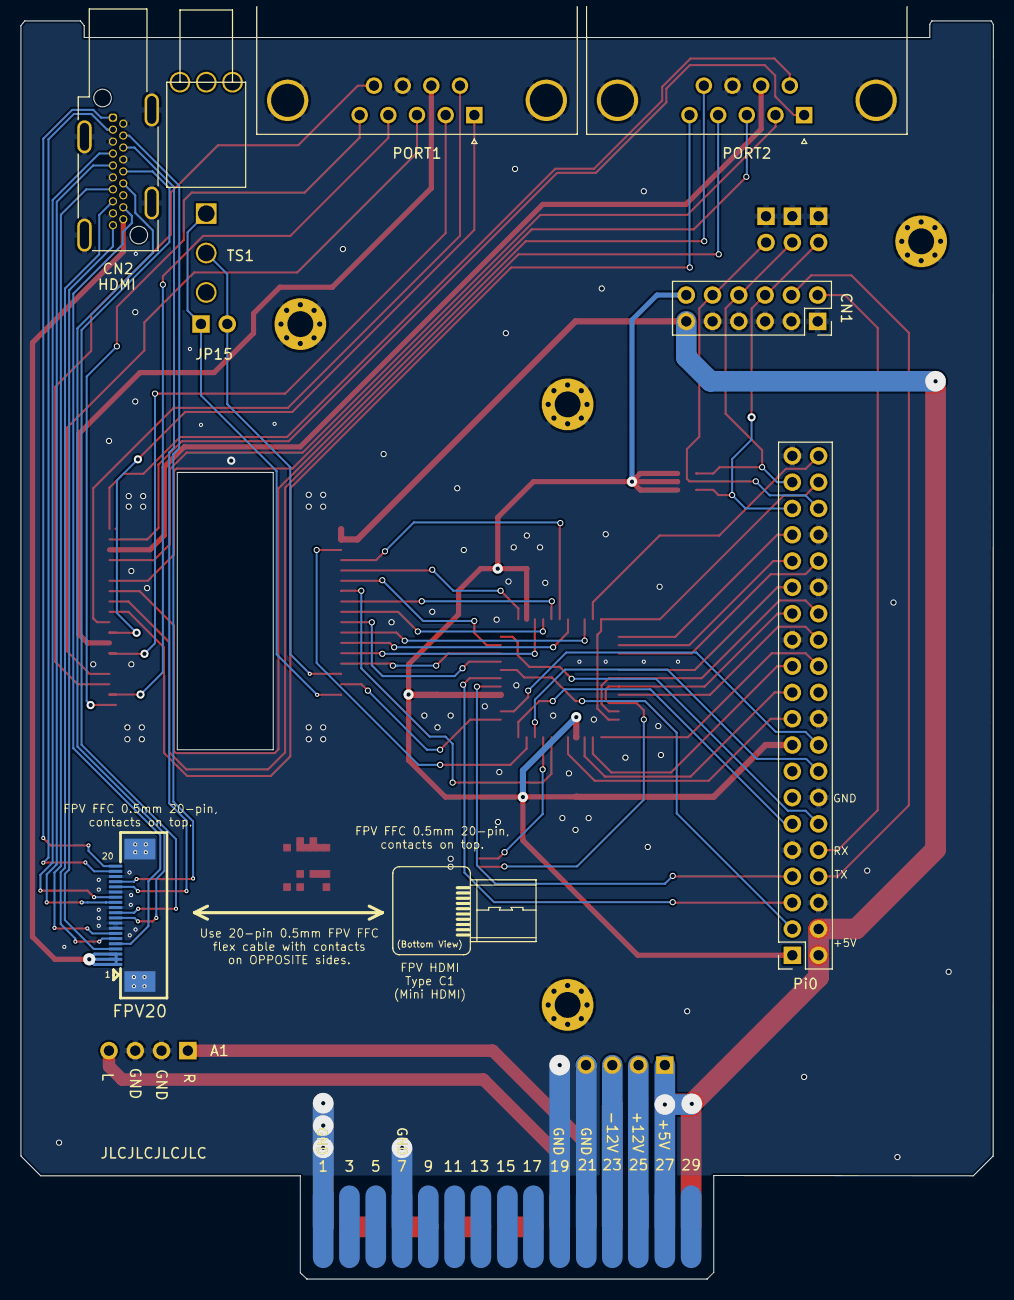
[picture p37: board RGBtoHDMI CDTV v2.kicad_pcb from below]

Board: 2 copper layers, 94.0 x 121.6 mm, 27 parts (7 on the bottom side), 81 nets.

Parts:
A1: Conn_01x04; PinHeader_1x04_P2.54mm_Vertical
BT1, BT2, BT3: Jumper_2_Open; PinHeader_1x02_P2.54mm_Vertical
C1, C2, C3: 100nF; C_0805_2012Metric_Pad1.18x1.45mm_HandSolder
CN1: Conn_02x06_Odd_Even; PinSocket_2x06_P2.54mm_Vertical
CN2: HDMI_A; HDMI_A_Kycon_KDMIX-SL1-NS-WS-B15_VerticalRightAngle
CN10: Conn_02x15_Odd_Even; CDTV_Video_Slot_30_pin
FFC1, FFC2: Conn_01x18; FPC-SMD_X10B25U18T
FPV20: Conn_01x20; XFCN_F0501-T-20-20T-R
H1, H2, H3, H4: MountingHole_Pad; MountingHole_2.5mm_Pad_Via
JP15: Conn_01x02; PinHeader_1x02_P2.54mm_Horizontal
P1: Conn_01x04; PinHeader_1x04_P2.54mm_Vertical
PORT1, PORT2: DB9_Male_MountingHoles; DSUB-9_Male_Horizontal_P2.77x2.84mm_EdgePinOffset7.70mm_Hou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
Pi0: Raspberry_Pi_2_3; PinSocket_2x20_P2.54mm_Vertical
RN1, RN2: 4K7; R_Array_Convex_4x0603
TS1: SW_SPDT; T8019L_T8020LB
U1: XC9572XL-10VQ44C or XC9572XL-10VQG44C; TQFP-44_10x10mm_P0.8mm
solarmon1: solarmon_logo; solarmon-logo-25mils

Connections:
+3V3: C1.1, C2.1, C3.1, CN1.12, Pi0.1, Pi0.17, RN1.6, RN1.7, RN1.8, U1.15, U1.26, U1.35
+5V: CN1.11, CN10.27, CN10.30, FFC1.17, FFC1.18, P1.1, Pi0.2, Pi0.4
+12V: CN10.25, P1.2
-12V: CN10.23, P1.3
/B0: FFC1.12, U1.18
/B1: FFC1.11, U1.38
/B2: FFC1.10, U1.37
/B3: FFC1.9, U1.30
/CLKEN: Pi0.28, U1.6, U1.10
/CSYNC: FFC1.3, U1.23
/DETECT: RN2.1, U1.19
/G0: FFC1.8, U1.42
/G1: FFC1.7, U1.40
/G2: FFC1.6, U1.36
/G3: FFC1.5, U1.31
/GPIO0: Pi0.27, RN2.2, U1.7, U1.9
/GPIO2: Pi0.3, U1.29
/GPIO3: Pi0.5, U1.28
/GPIO4: Pi0.7, U1.27
/GPIO5: Pi0.29, U1.5
/GPIO6: Pi0.31, U1.2
/GPIO7: Pi0.26, U1.8
/GPIO8: Pi0.24, U1.12
/GPIO9: Pi0.21, U1.14
/GPIO10: Pi0.19, U1.16
/GPIO11: Pi0.23, U1.13
/GPIO12: Pi0.32, U1.3
/GPIO13: Pi0.33, U1.1
/GPIO14: CN1.4, Pi0.8
/GPIO15: CN1.2, Pi0.10
/GPIO16: BT1.2, CN1.10, Pi0.36, RN1.2
/GPIO17: Pi0.11, U1.22
/GPIO18: Pi0.12, U1.33
/GPIO19: BT3.2, CN1.6, Pi0.35, RN1.3
/GPIO20: Pi0.38, U1.11, U1.44
/GPIO21: Pi0.40, U1.43
/GPIO23: Pi0.16, U1.20
/GPIO24: Pi0.18, U1.24
/GPIO26: BT2.2, CN1.8, Pi0.37, RN1.1
/R0: FFC1.16, U1.21
/R1: FFC1.15, U1.39
/R2: FFC1.14, U1.34
/R3: FFC1.13, U1.32
AB: CN10.12, CN10.14
AC: CN10.16, CN10.18
AG: CN10.8, CN10.10
AR: CN10.4, CN10.6
AUDL: A1.4, CN10.20
AUDR: A1.1, CN10.22
GND: A1.2, A1.3, BT1.1, BT2.1, BT3.1, C1.2, C2.2, C3.2, CN1.1, CN1.3, CN1.5, CN1.7, CN1.9, CN2.2, CN2.5, CN2.8, CN2.11, CN2.17, CN2.SH, CN10.1, CN10.2, CN10.7, CN10.19, CN10.21, CN10.24, FFC1.1, FFC1.MP, FFC2.5, FFC2.14, FFC2.MP, FPV20.8, FPV20.9, FPV20.12, FPV20.15, FPV20.18, FPV20.MP, H1.1, H2.1, H3.1, H4.1, P1.4, PORT1.0, PORT1.8, PORT2.0, PORT2.8, Pi0.6, Pi0.9, Pi0.14, Pi0.20, Pi0.25, Pi0.30, Pi0.34, Pi0.39, RN2.7, RN2.8, U1.4, U1.17, U1.25
HDMI_1_D2+: CN2.1, FPV20.20
HDMI_3_D2-: CN2.3, FPV20.19
HDMI_4_D1+: CN2.4, FPV20.17
HDMI_5V: CN2.18, FPV20.1, FPV20.2, FPV20.3
HDMI_6_D1-: CN2.6, FPV20.16
HDMI_7_D0+: CN2.7, FPV20.14
HDMI_9_D0-: CN2.9, FPV20.13
HDMI_10_CK+: CN2.10, FPV20.11
HDMI_12_CK-: CN2.12, FPV20.10
HDMI_13_CEC: CN2.13, FPV20.7
HDMI_15_SCL: CN2.15, FPV20.6
HDMI_16_SDA: CN2.16, FPV20.5
HDMI_19_HPD: CN2.19, FPV20.4
JP15_Pin1: FFC1.2, JP15.1, TS1.1
JP15_Pin2: FFC1.4, JP15.2, TS1.2
Port1_1: FFC2.11, PORT1.1
Port1_2: FFC2.13, PORT1.2
Port1_3: FFC2.15, PORT1.3
Port1_4: FFC2.17, PORT1.4
Port1_5: FFC2.18, PORT1.5
Port1_6: FFC2.10, PORT1.6
Port1_7: FFC2.12, PORT1.7
Port1_9: FFC2.16, PORT1.9
Port2_1: FFC2.2, PORT2.1
Port2_2: FFC2.4, PORT2.2
Port2_3: FFC2.6, PORT2.3
Port2_4: FFC2.8, PORT2.4
Port2_5: FFC2.9, PORT2.5
Port2_6: FFC2.1, PORT2.6
Port2_7: FFC2.3, PORT2.7
Port2_9: FFC2.7, PORT2.9

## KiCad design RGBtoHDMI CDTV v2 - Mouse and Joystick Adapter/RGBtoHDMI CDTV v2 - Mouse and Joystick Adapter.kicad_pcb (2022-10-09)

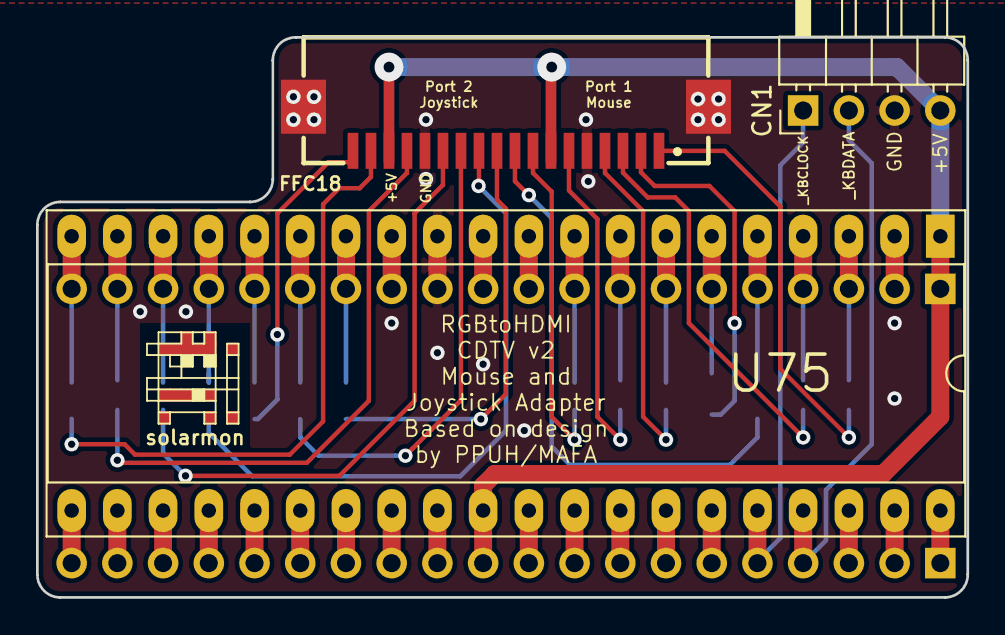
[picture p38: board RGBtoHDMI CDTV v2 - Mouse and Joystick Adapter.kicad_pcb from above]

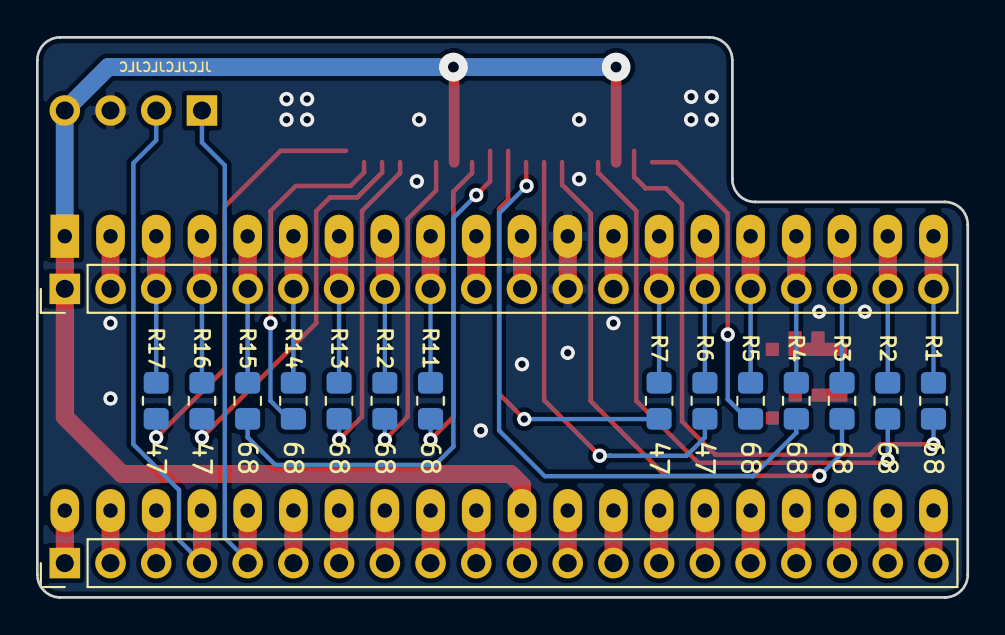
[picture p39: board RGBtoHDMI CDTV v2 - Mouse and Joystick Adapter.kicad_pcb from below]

Board: 2 copper layers, 51.7 x 31.1 mm, 20 parts (16 on the bottom side), 53 nets.

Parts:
CN1: Conn_01x04; PinHeader_1x04_P2.54mm_Horizontal
FFC18: FFC_18; FPC-SMD_X10B25U18T
J1, J2: Conn_01x20; PinHeader_1x20_P2.54mm_Vertical
R1, R2, R3, R4, R5, R11, R12, R13, R14, R15: 68; R_0805_2012Metric_Pad1.20x1.40mm_HandSolder
R6, R7, R16, R17: 47; R_0805_2012Metric_Pad1.20x1.40mm_HandSolder
U75: Conn_02x20_Counter_Clockwise; DIP-40_W15.24mm_Socket_LongPads
solarmon1: solarmon_logo; solarmon-logo-25mils

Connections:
+5V: CN1.4, FFC18.7, FFC18.16, J1.1, J2.11, U75.1, U75.30
GND: CN1.3, FFC18.5, FFC18.14, FFC18.MP, J1.12, U75.12
unnamed: J1.2, U75.2
unnamed: J1.3, R17.2, U75.3
unnamed: J1.4, R16.2, U75.4
unnamed: J1.5, R15.2, U75.5
unnamed: J1.6, R14.2, U75.6
unnamed: J1.7, R13.2, U75.7
unnamed: J1.8, R12.2, U75.8
unnamed: J1.9, R11.2, U75.9
unnamed: J1.10, U75.10
unnamed: J1.11, U75.11
unnamed: J1.13, U75.13
unnamed: J1.14, R7.2, U75.14
unnamed: J1.15, R6.2, U75.15
unnamed: J1.16, R5.2, U75.16
unnamed: J1.17, R4.2, U75.17
unnamed: J1.18, R3.2, U75.18
unnamed: J1.19, R2.2, U75.19
unnamed: J1.20, R1.2, U75.20
unnamed: J2.1, U75.40
unnamed: J2.2, U75.39
unnamed: J2.3, U75.38
unnamed: J2.6, U75.35
unnamed: J2.7, U75.34
unnamed: J2.8, U75.33
unnamed: J2.9, U75.32
unnamed: J2.10, U75.31
unnamed: J2.12, U75.29
unnamed: J2.13, U75.28
unnamed: J2.14, U75.27
unnamed: J2.15, U75.26
unnamed: J2.16, U75.25
unnamed: J2.17, U75.24
unnamed: J2.18, U75.23
unnamed: J2.19, U75.22
unnamed: J2.20, U75.21
Port1_1_YB1: FFC18.8, R11.1
Port1_2_XA1: FFC18.6, R12.1
Port1_3_YA1: FFC18.4, R13.1
Port1_4_XB1: FFC18.2, R14.1
Port1_5_POT0X: FFC18.1, R17.1
Port1_6_FIRE0: FFC18.9, R15.1
Port1_9_POT0Y: FFC18.3, R16.1
Port2_1_YB2: FFC18.17, R1.1
Port2_2_XA2: FFC18.15, R2.1
Port2_3_YA2: FFC18.13, R3.1
Port2_4_XB2: FFC18.11, R4.1
Port2_5_POT1X: FFC18.10, R7.1
Port2_6_FIRE1: FFC18.18, R5.1
Port2_9_POT1Y: FFC18.12, R6.1
_KBCLOCK: CN1.1, J2.5, U75.36
_KBDATA: CN1.2, J2.4, U75.37

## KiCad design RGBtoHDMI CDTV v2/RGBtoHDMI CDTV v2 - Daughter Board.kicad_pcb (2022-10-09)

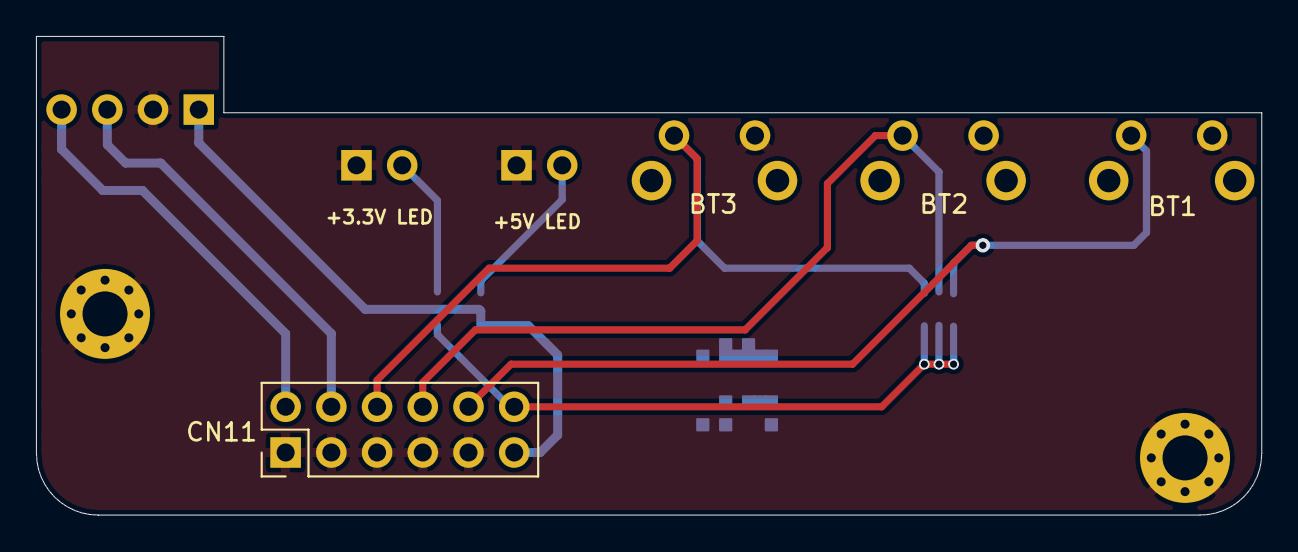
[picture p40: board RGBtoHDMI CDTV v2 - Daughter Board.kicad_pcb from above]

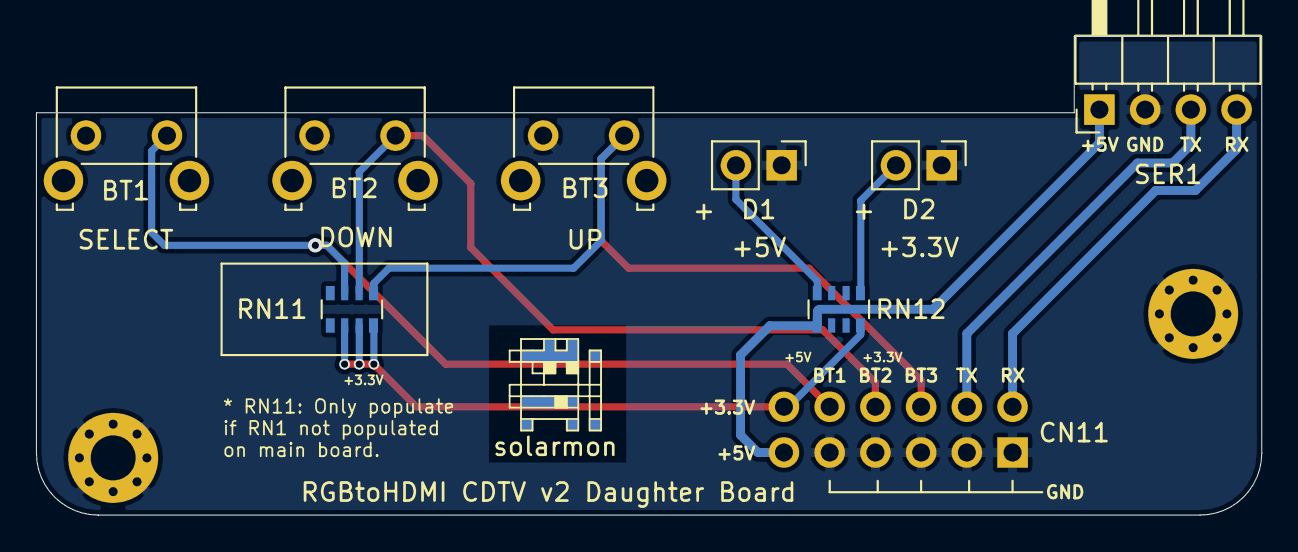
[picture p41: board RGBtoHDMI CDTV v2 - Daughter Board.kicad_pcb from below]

Board: 2 copper layers, 68.1 x 26.6 mm, 12 parts (9 on the bottom side), 10 nets.

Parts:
BT1, BT2, BT3: SW_Push; SW_Tactile_SKHH_Angled
CN11: Conn_02x06_Odd_Even; PinHeader_2x06_P2.54mm_Vertical
D1, D2: LED; PinHeader_1x02_P2.54mm_Vertical
H1, H2: MountingHole_Pad; MountingHole_2.5mm_Pad_Via
RN11, RN12: 4K7; R_Array_Convex_4x0603
SER1: Conn_01x04; PinHeader_1x04_P2.54mm_Horizontal
solarmon1: solarmon_logo; solarmon-logo-25mils

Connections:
+3V3: CN11.12, RN11.6, RN11.7, RN11.8, RN12.4
+5V: CN11.11, RN12.1, SER1.1
GND: BT1.1, BT2.1, BT3.1, CN11.1, CN11.3, CN11.5, CN11.7, CN11.9, D1.1, D2.1, H1.1, H2.1, SER1.2
GPIO14: CN11.4, SER1.3
GPIO15: CN11.2, SER1.4
GPIO16: BT1.2, CN11.10, RN11.3
GPIO19: BT3.2, CN11.6, RN11.1
GPIO26: BT2.2, CN11.8, RN11.2
unnamed: D1.2, RN12.8
unnamed: D2.2, RN12.5

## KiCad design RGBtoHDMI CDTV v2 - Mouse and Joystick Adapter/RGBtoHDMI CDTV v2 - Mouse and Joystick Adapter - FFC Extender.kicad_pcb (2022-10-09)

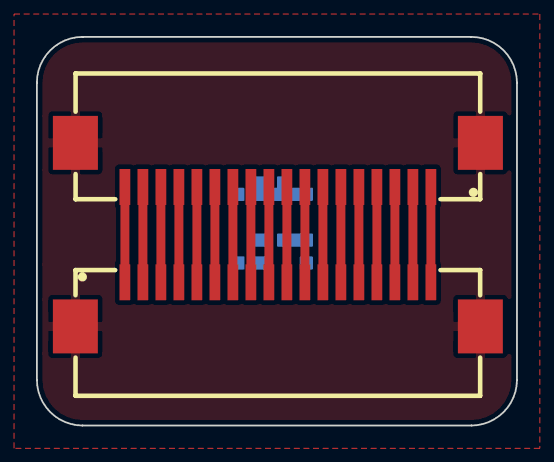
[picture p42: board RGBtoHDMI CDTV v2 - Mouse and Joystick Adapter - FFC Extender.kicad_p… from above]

Board: 2 copper layers, 26.7 x 21.6 mm, 3 parts (1 on the bottom side), 19 nets.

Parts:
FFC1, FFC2: FFC_18; FPC-SMD_X10B25U18T
solarmon1: solarmon_logo; solarmon-logo-25mils

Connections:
GND: FFC1.MP, FFC2.MP
unnamed: FFC1.1, FFC2.18
unnamed: FFC1.2, FFC2.17
unnamed: FFC1.3, FFC2.16
unnamed: FFC1.4, FFC2.15
unnamed: FFC1.5, FFC2.14
unnamed: FFC1.6, FFC2.13
unnamed: FFC1.7, FFC2.12
unnamed: FFC1.8, FFC2.11
unnamed: FFC1.9, FFC2.10
unnamed: FFC1.10, FFC2.9
unnamed: FFC1.11, FFC2.8
unnamed: FFC1.12, FFC2.7
unnamed: FFC1.13, FFC2.6
unnamed: FFC1.14, FFC2.5
unnamed: FFC1.15, FFC2.4
unnamed: FFC1.16, FFC2.3
unnamed: FFC1.17, FFC2.2
unnamed: FFC1.18, FFC2.1

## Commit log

2022-04-06 Annotated flex cables
2022-10-09 Uploaded design files
    Uploaded design files for:
    * RGBtoHDMI CDTV v2
    * RGBtoHDMI CDTV v2 - Denise Breakout
    * RGBtoHDMI CDTV v2 - Mouse and Joystick Adapter
    [RGBtoHDMI CDTV v2 - Daughter Board-B_Cu.dxf, RGBtoHDMI CDTV v2 - Daughter Board-B_Mask.dxf, RGBtoHDMI CDTV v2 - Daughter Board-B_SilkS.dxf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]
2022-10-09 Added fully assembled pictures
2022-10-10 Convert daughterboard schematic to KiCAD v6
    [RGBtoHDMI CDTV v2 - Daughter Board.kicad_sch]
